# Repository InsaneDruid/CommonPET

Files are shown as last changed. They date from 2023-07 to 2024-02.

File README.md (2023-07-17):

# The CommonPET
The CommonPET is a 100% compatible replica of the SuperPet combo board for PET/CBM 8032 computers from 1981.
It implements all the features, including the 64K RAM addon, compatibility for the OS9 MMU well as the support for the internal RS-232 connector.

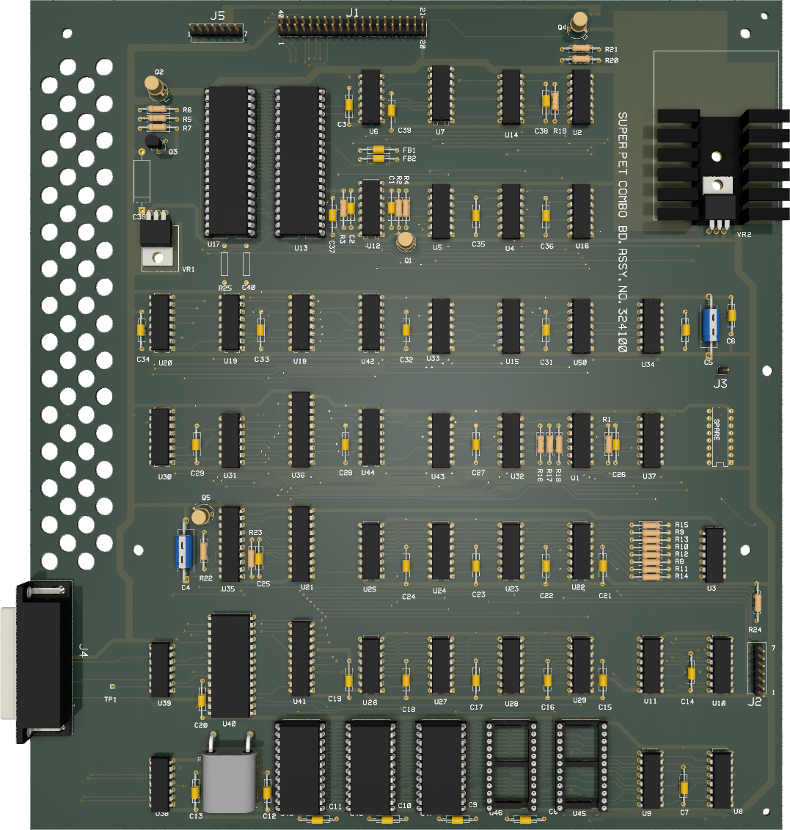
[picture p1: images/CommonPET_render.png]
CommonPET render


Most of the components are readily available. Chips not available from Mouser or Digikey can still be purchased as NOS from a variety of sources.

[Schematic](https://github.com/InsaneDruid/CommonPET/blob/main/CommonPET.pdf "Schematic")  

[Bill of Materials](https://htmlpreview.github.io/?https://github.com/InsaneDruid/CommonPET/blob/main/bom/CommonPET_bom.html "Bill of Materials")
## The Firmware
The Firmware of the SuperPET is available at zimmers.net: http://www.zimmers.net/anonftp/pub/cbm/firmware/computers/pet/SuperPET/index.html

UA3: characters.901640-01.bin (PETside CharROM):

U47: waterloo-a000-bfff.970018-12.bin

U48: waterloo-c000-dfff.970019-12.bin

U49: waterloo-e000-ffff-970034-12.bin (50Hz Version)

U49: waterloo-e000-ffff.970020-12.bin (60Hz Version)

Adapters to use 2764 EPROM work, 27hc641 that are programmed to be pin compatible to 2364 are recommended.

## The RS232 interface
CBM in its infinite wisdom only provided +5V and -9V for the 1488 line driver. A low voltage 1488E or 14C88 is recommended.

## The OS/9 MMU addon board
A replica of the OS/9 addon board can be found in the [os9_mmu folder](https://github.com/InsaneDruid/CommonPET/blob/main/os9_mmu/ "os9_mmu folder")

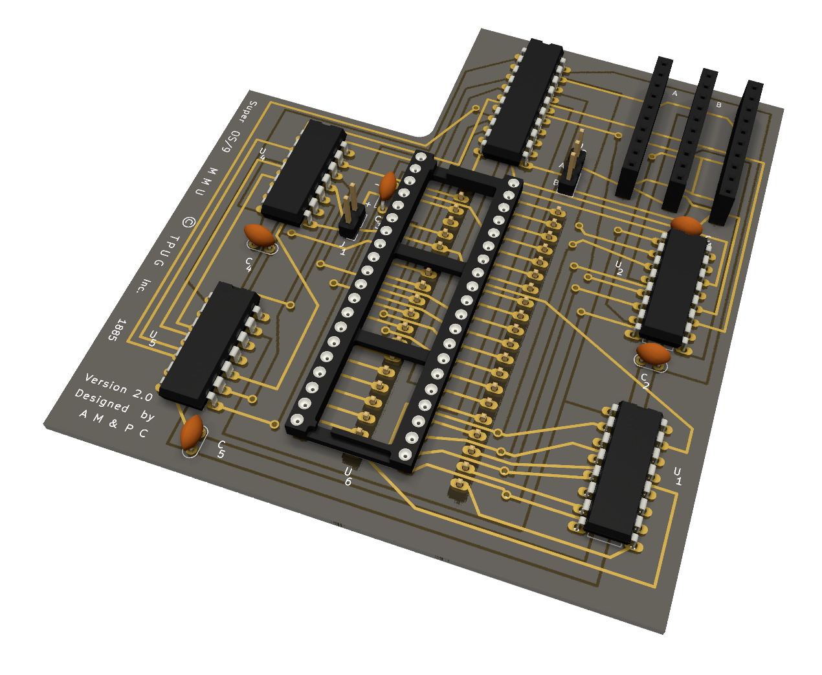
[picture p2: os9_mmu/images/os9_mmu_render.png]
OS/9 MMU addon board render
 

## The License
This work is licensed under a Creative Commons Attribution-ShareAlike 4.0 International License.  
See https://creativecommons.org/licenses/by-sa/4.0/.

## The Credits
This work would not have been possible without the help from a bunch of amazing people from [VzEkC e. V. forums](https://forum.classic-computing.de/forum/ "forum.classic-computing.de"). Many thanks go out to:

* *for(;;)* - for creating the amazing µMMF project that inspired this work
* *vossi* - for providing excellent images of a ASSY 324100 board
* *CBM_Ba* and *Richi*- for building and testing the first prototype

Special credits go out to *Mike Naberezny* for researching the OS/9 MMU schematics

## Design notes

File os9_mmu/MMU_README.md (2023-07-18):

## The OS/9 MMU
In the SuperPet system, the additional 64K of RAM is only accessible in 16 banks of 4KB, mapped in the $9000-9FFF address range (usually reserved for option ROMs) with a bank select register $EFFC.

The OS/9 MMU, designed by members of the Toronto PET Users Group (TPUG) expands the SuperPET expansion RAM bank select latch at $EFFC.

With the MMU installed, when bit 5 is set at $EFFC, the 6809 can access all of the 64K in the $0000-FFFF continuous address range.

# The three connector rows

The MMU interfaces with the SuperPet boards using the 6809 processor socket and the socket of the 74LS273 $EFFC latch IC controlling the memory bank select lines.

For the original, two-board SuperPet (U9) and the Comboboard Version (U36) different units of the total of eight flip flops contained in this IC had been used. Luckily, only one of the signals needed (EFFC) isn't mirror-symmetric between the two variants.

Thus, using only 3 Rows of connectors and one jumper is enough to be able to interface with either version of the SuperPet boards.

* For *ComboBoard SuperPets*, connect the ribbon cable going to the U36 Socket on the leftmost rows and set the jumper to 1-2. (Option A)
  
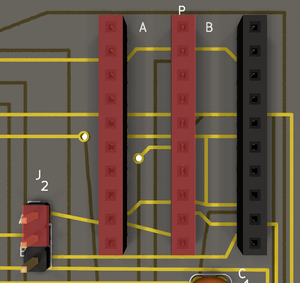
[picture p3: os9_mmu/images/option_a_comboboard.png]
OS/9 MMU addon board Option A
 
* For *two-board SuperPets*, connect the ribbon cable going to the U9 Socket on the rightmost rows and set the jumper to 2-3. (Option B)
  
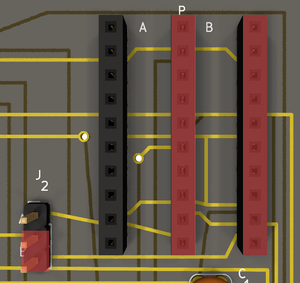
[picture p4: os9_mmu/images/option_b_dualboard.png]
OS/9 MMU addon board Option B


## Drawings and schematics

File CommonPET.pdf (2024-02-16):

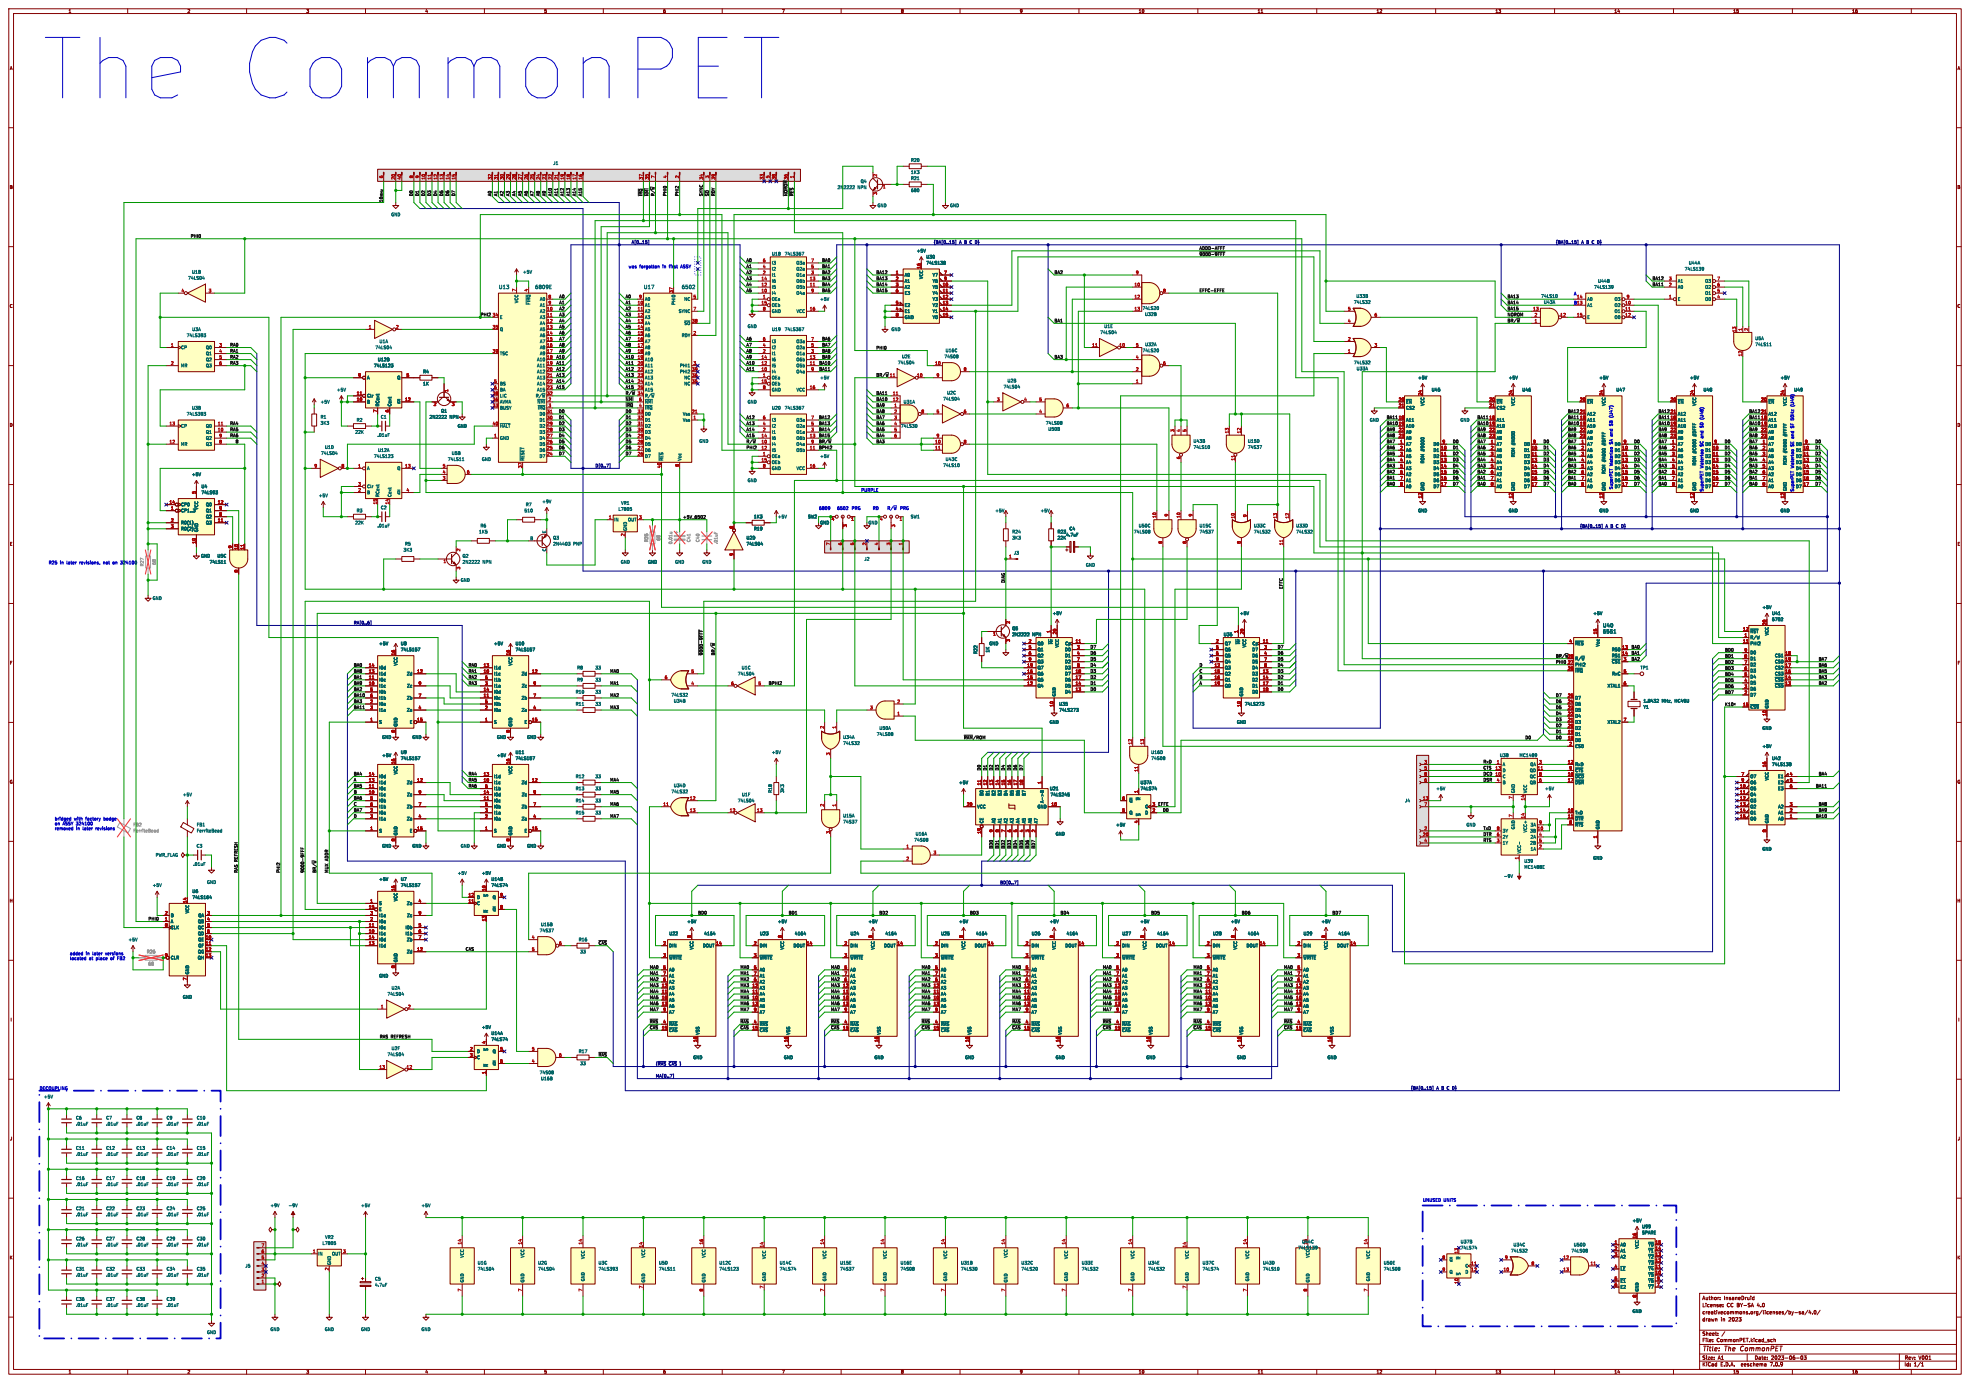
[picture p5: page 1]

bridged with factory bodge
on ASSY 324100
FB2 FerriteBead+5V
FerriteBead GND

removed in later revisions

8 A5 10 A4 11 A3 12 A6 13 DOUT 14 ~{CAS} 15 VSS 16 DIN 2 ~{WRITE} 3 ~{RAS} 4 A0 5 A2 6 A1 7 A7 9 U23 4164 +5VGND VCC 14 GND

8 A5 10 A4 11 A3 12 A6 13 DOUT 14 ~{CAS} 15 VSS 16 DIN 2 ~{WRITE} 3 ~{RAS} 4 A0 5 A2 6 A1 7 A7 9 U22 4164 VCC

8 A5 10 A4 11 A3 12 A6 13 DOUT 14 ~{CAS} 15 VSS 16 DIN 2 ~{WRITE} 3 ~{RAS} 4 A0 5 A2 6 A1 7 A7 9 GND

added in later versions

File: CommonPET.kicad_sch Sheet: / drawn in 2023

Id: 1/1 Title: The CommonPET

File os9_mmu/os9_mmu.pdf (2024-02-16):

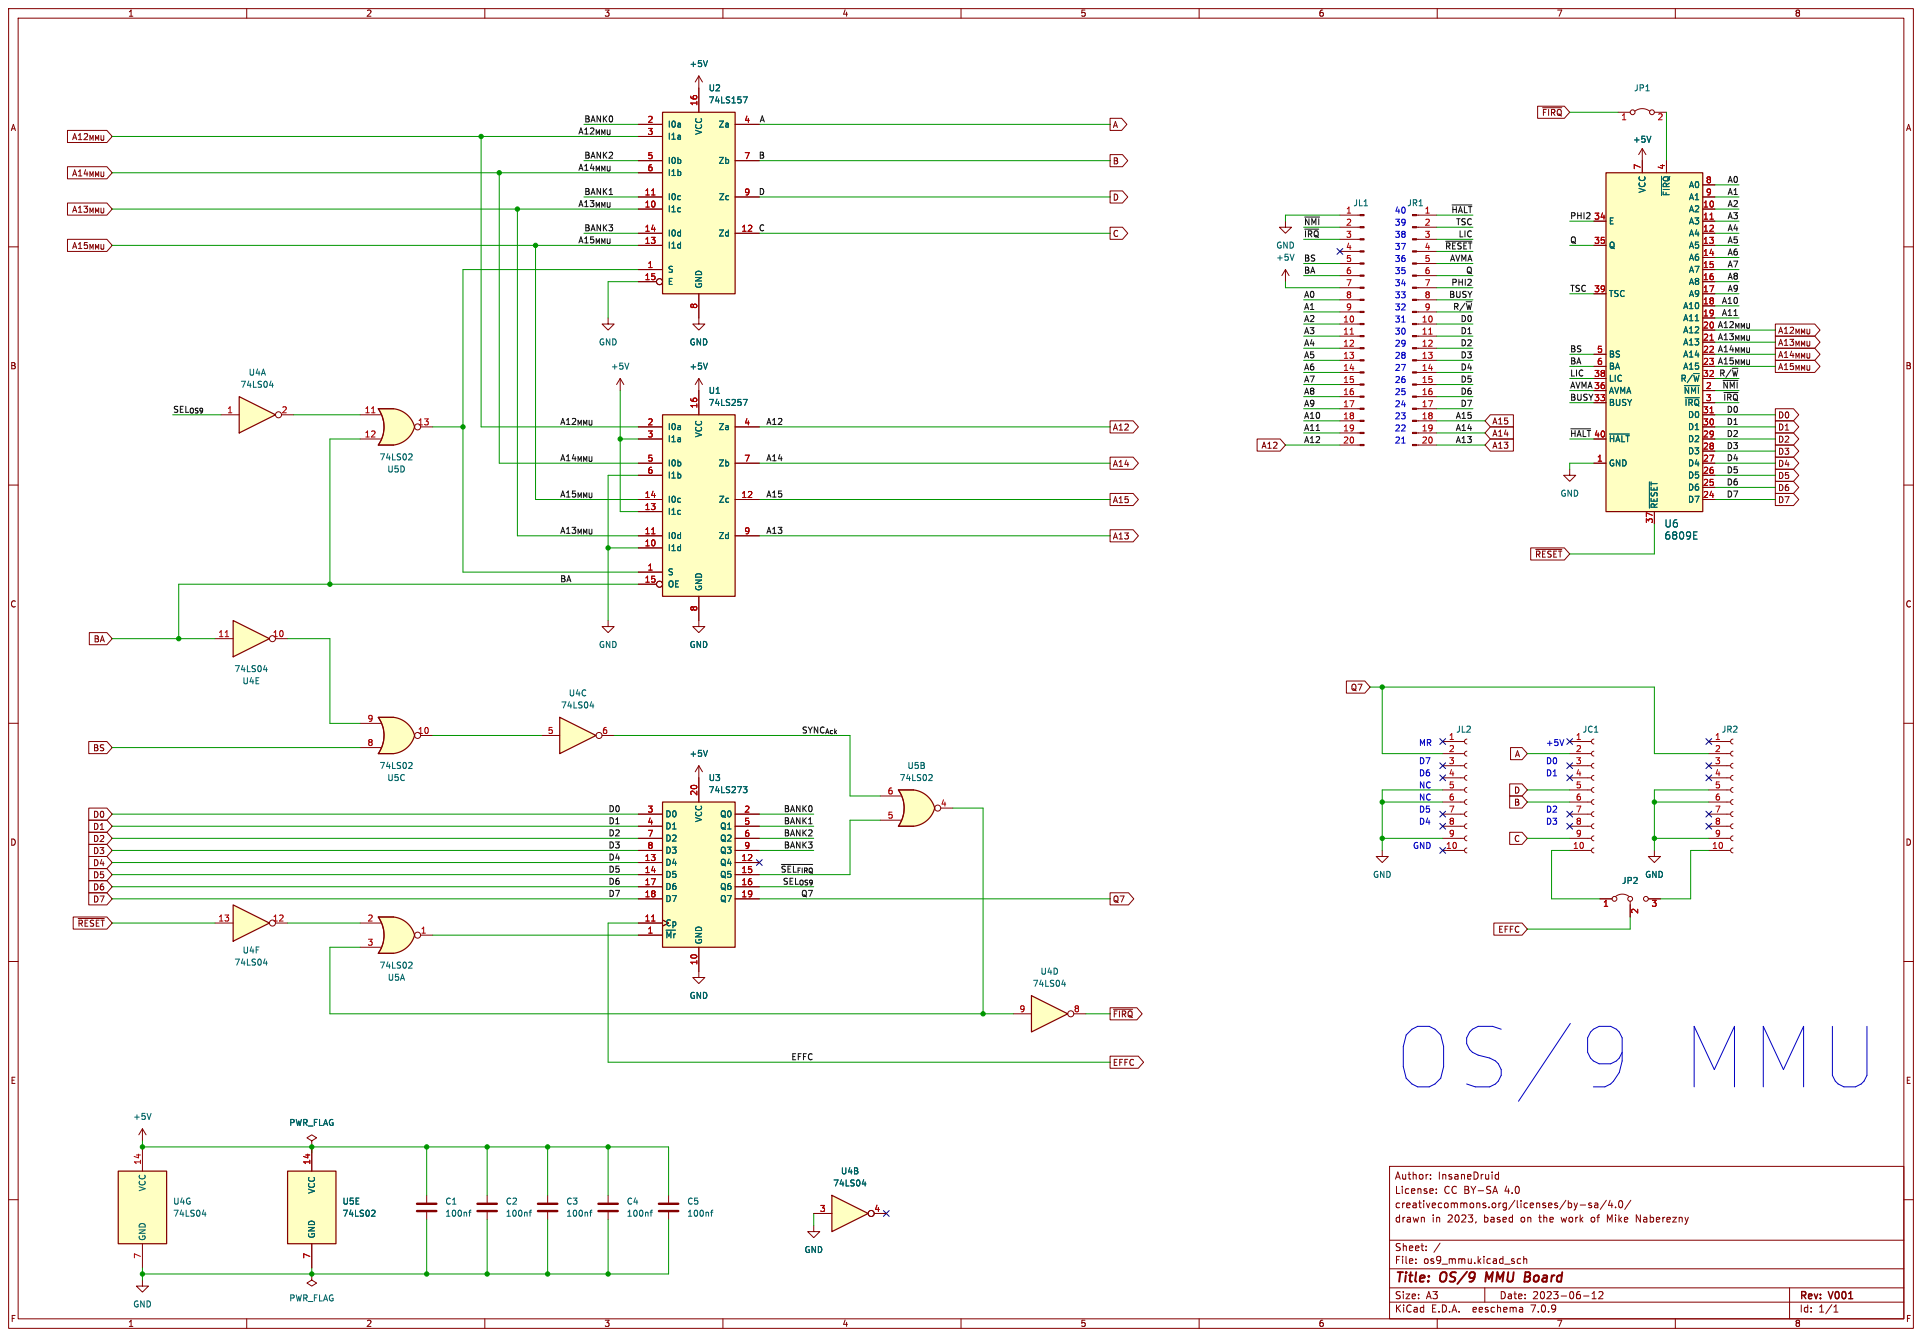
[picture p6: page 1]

Id: 1/1 Title: OS/9 MMU Board

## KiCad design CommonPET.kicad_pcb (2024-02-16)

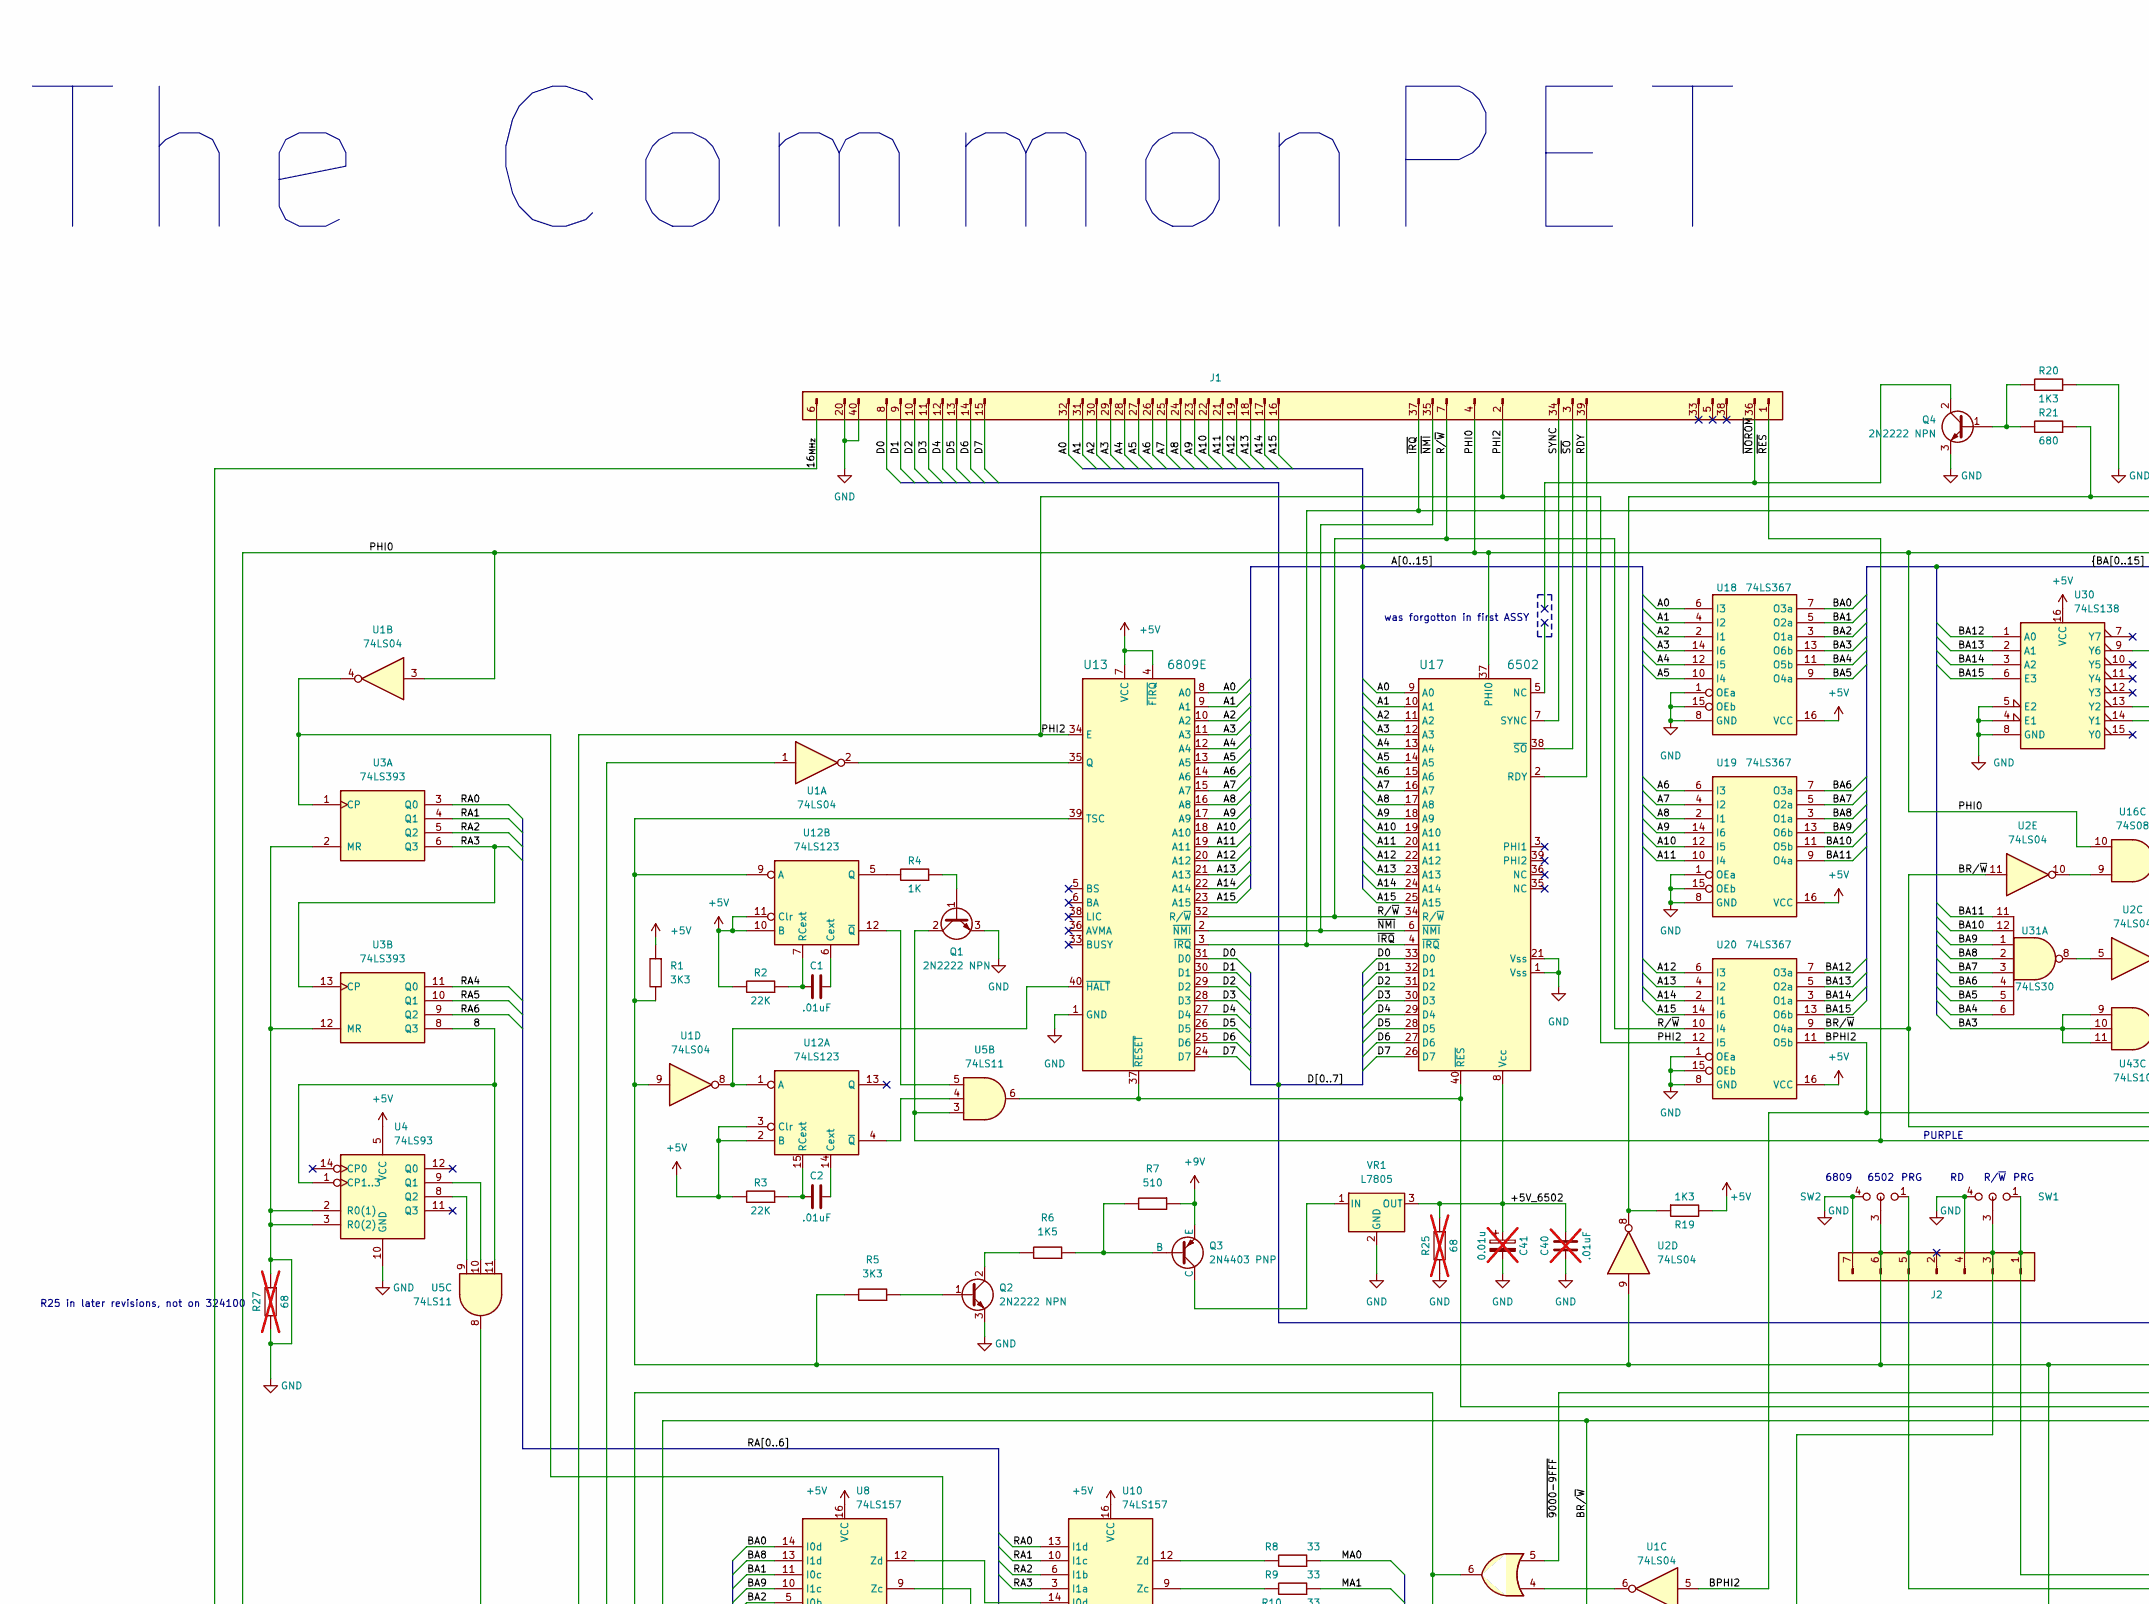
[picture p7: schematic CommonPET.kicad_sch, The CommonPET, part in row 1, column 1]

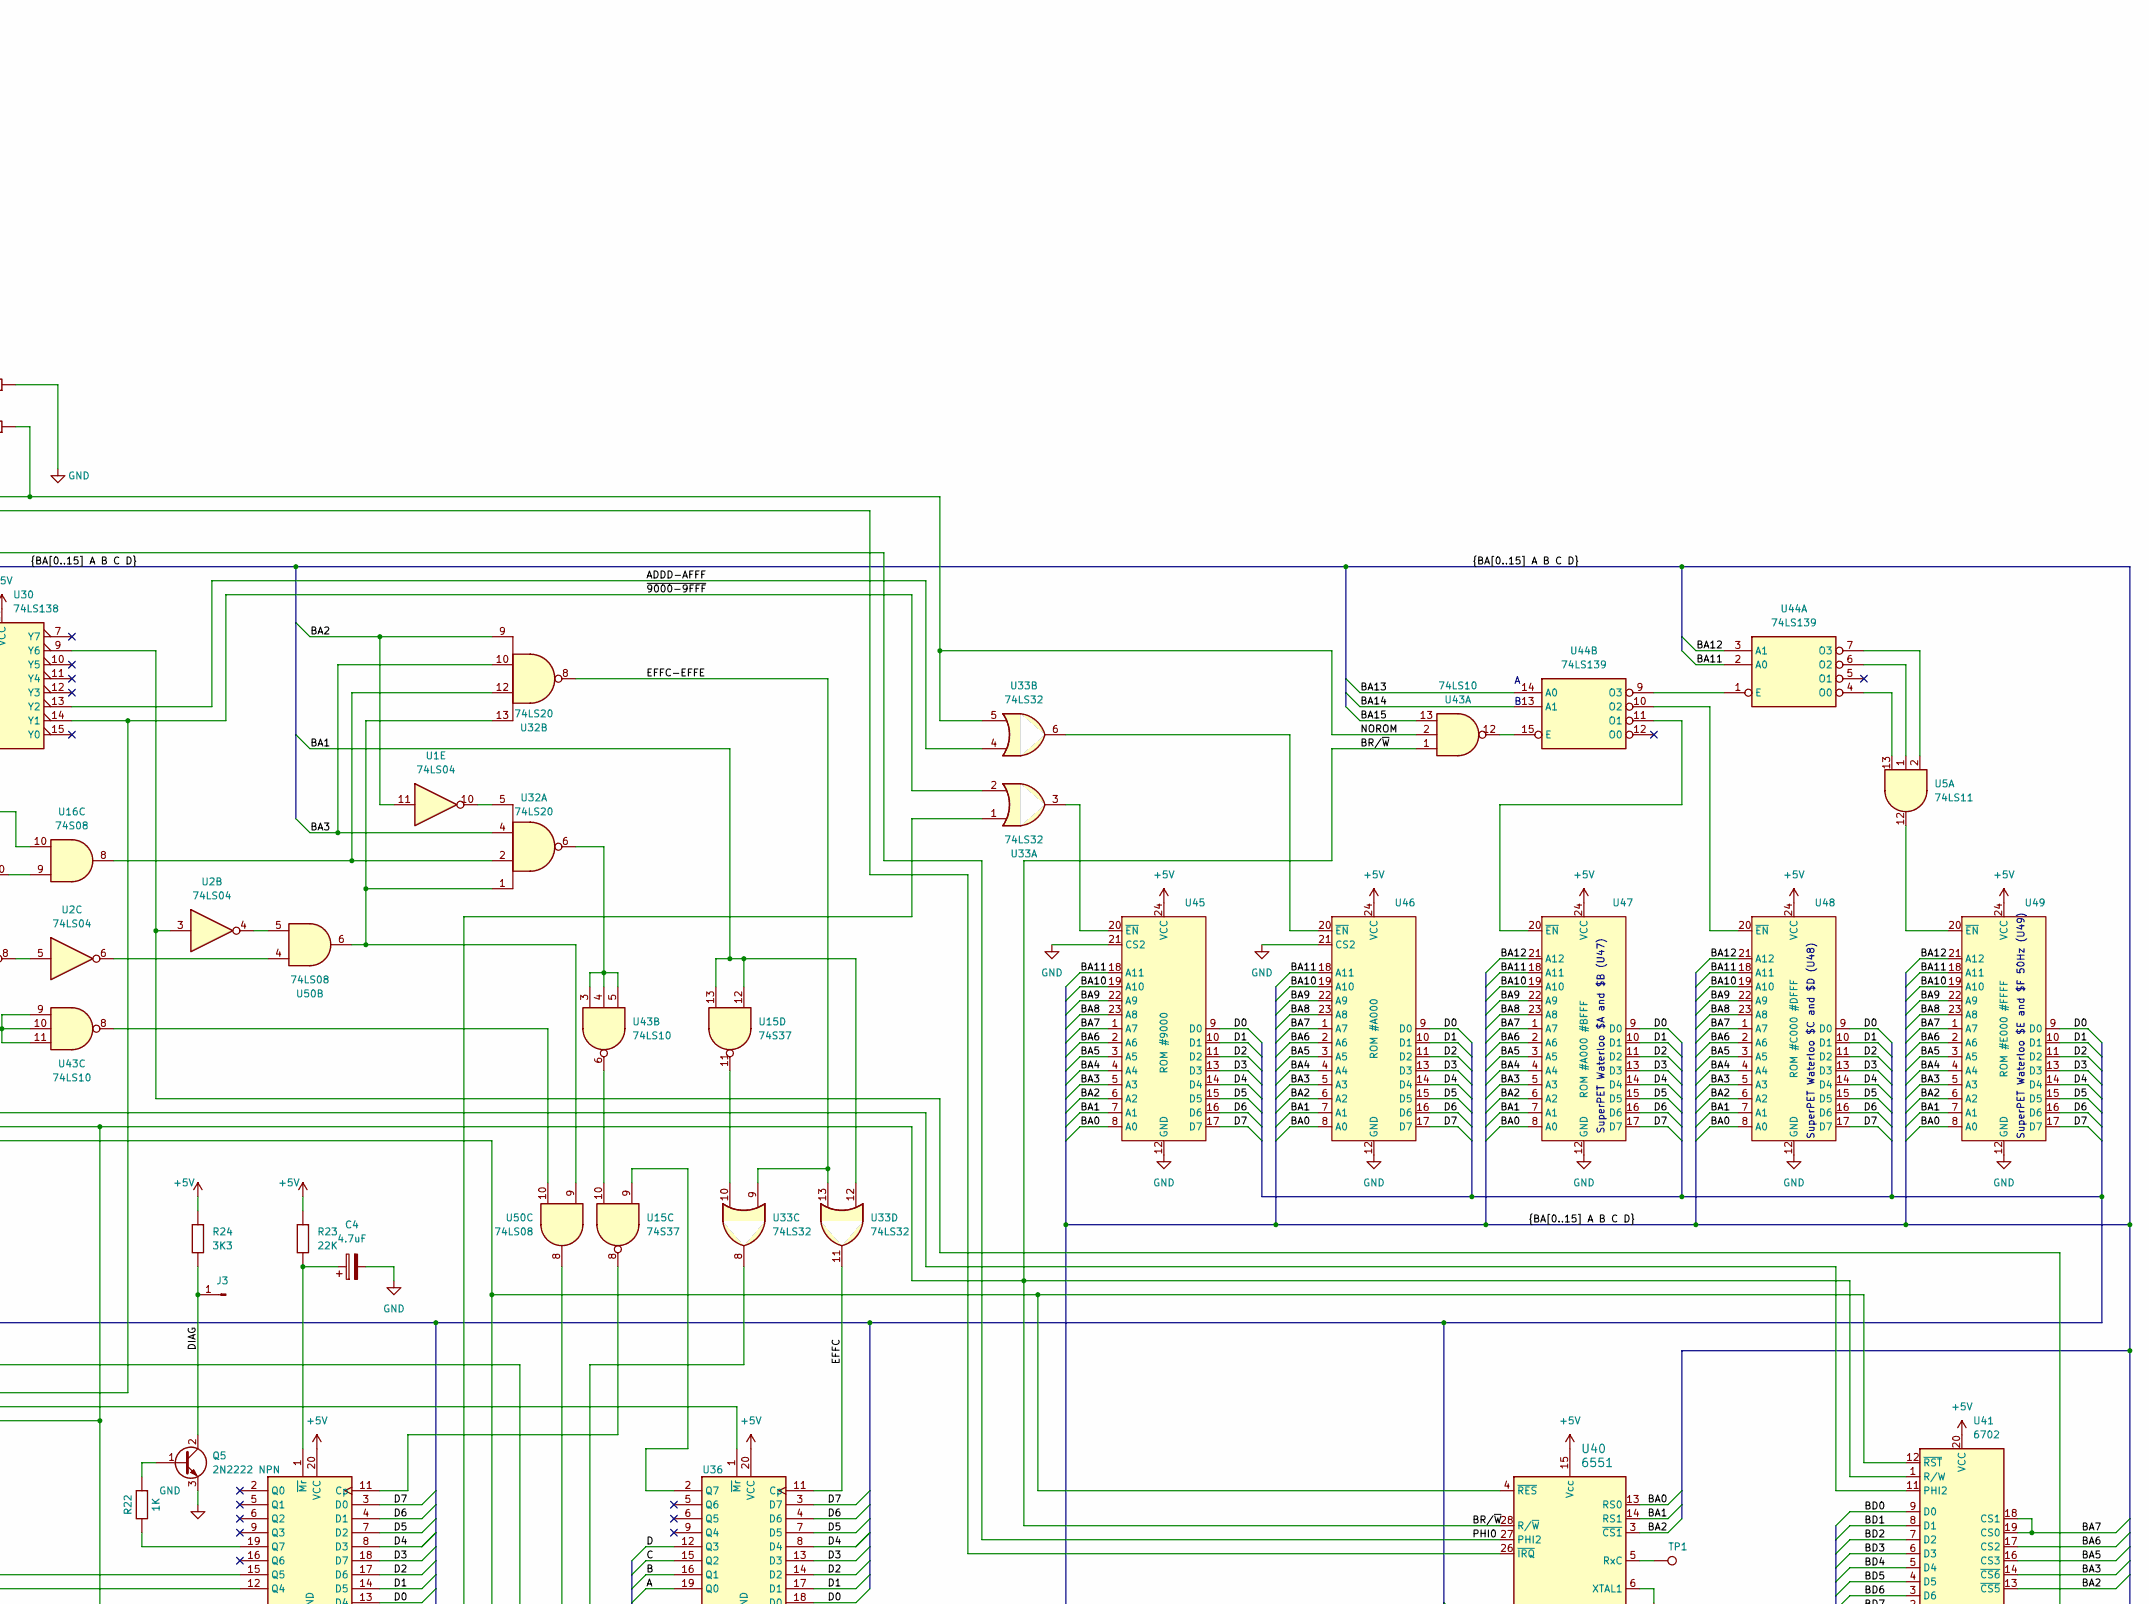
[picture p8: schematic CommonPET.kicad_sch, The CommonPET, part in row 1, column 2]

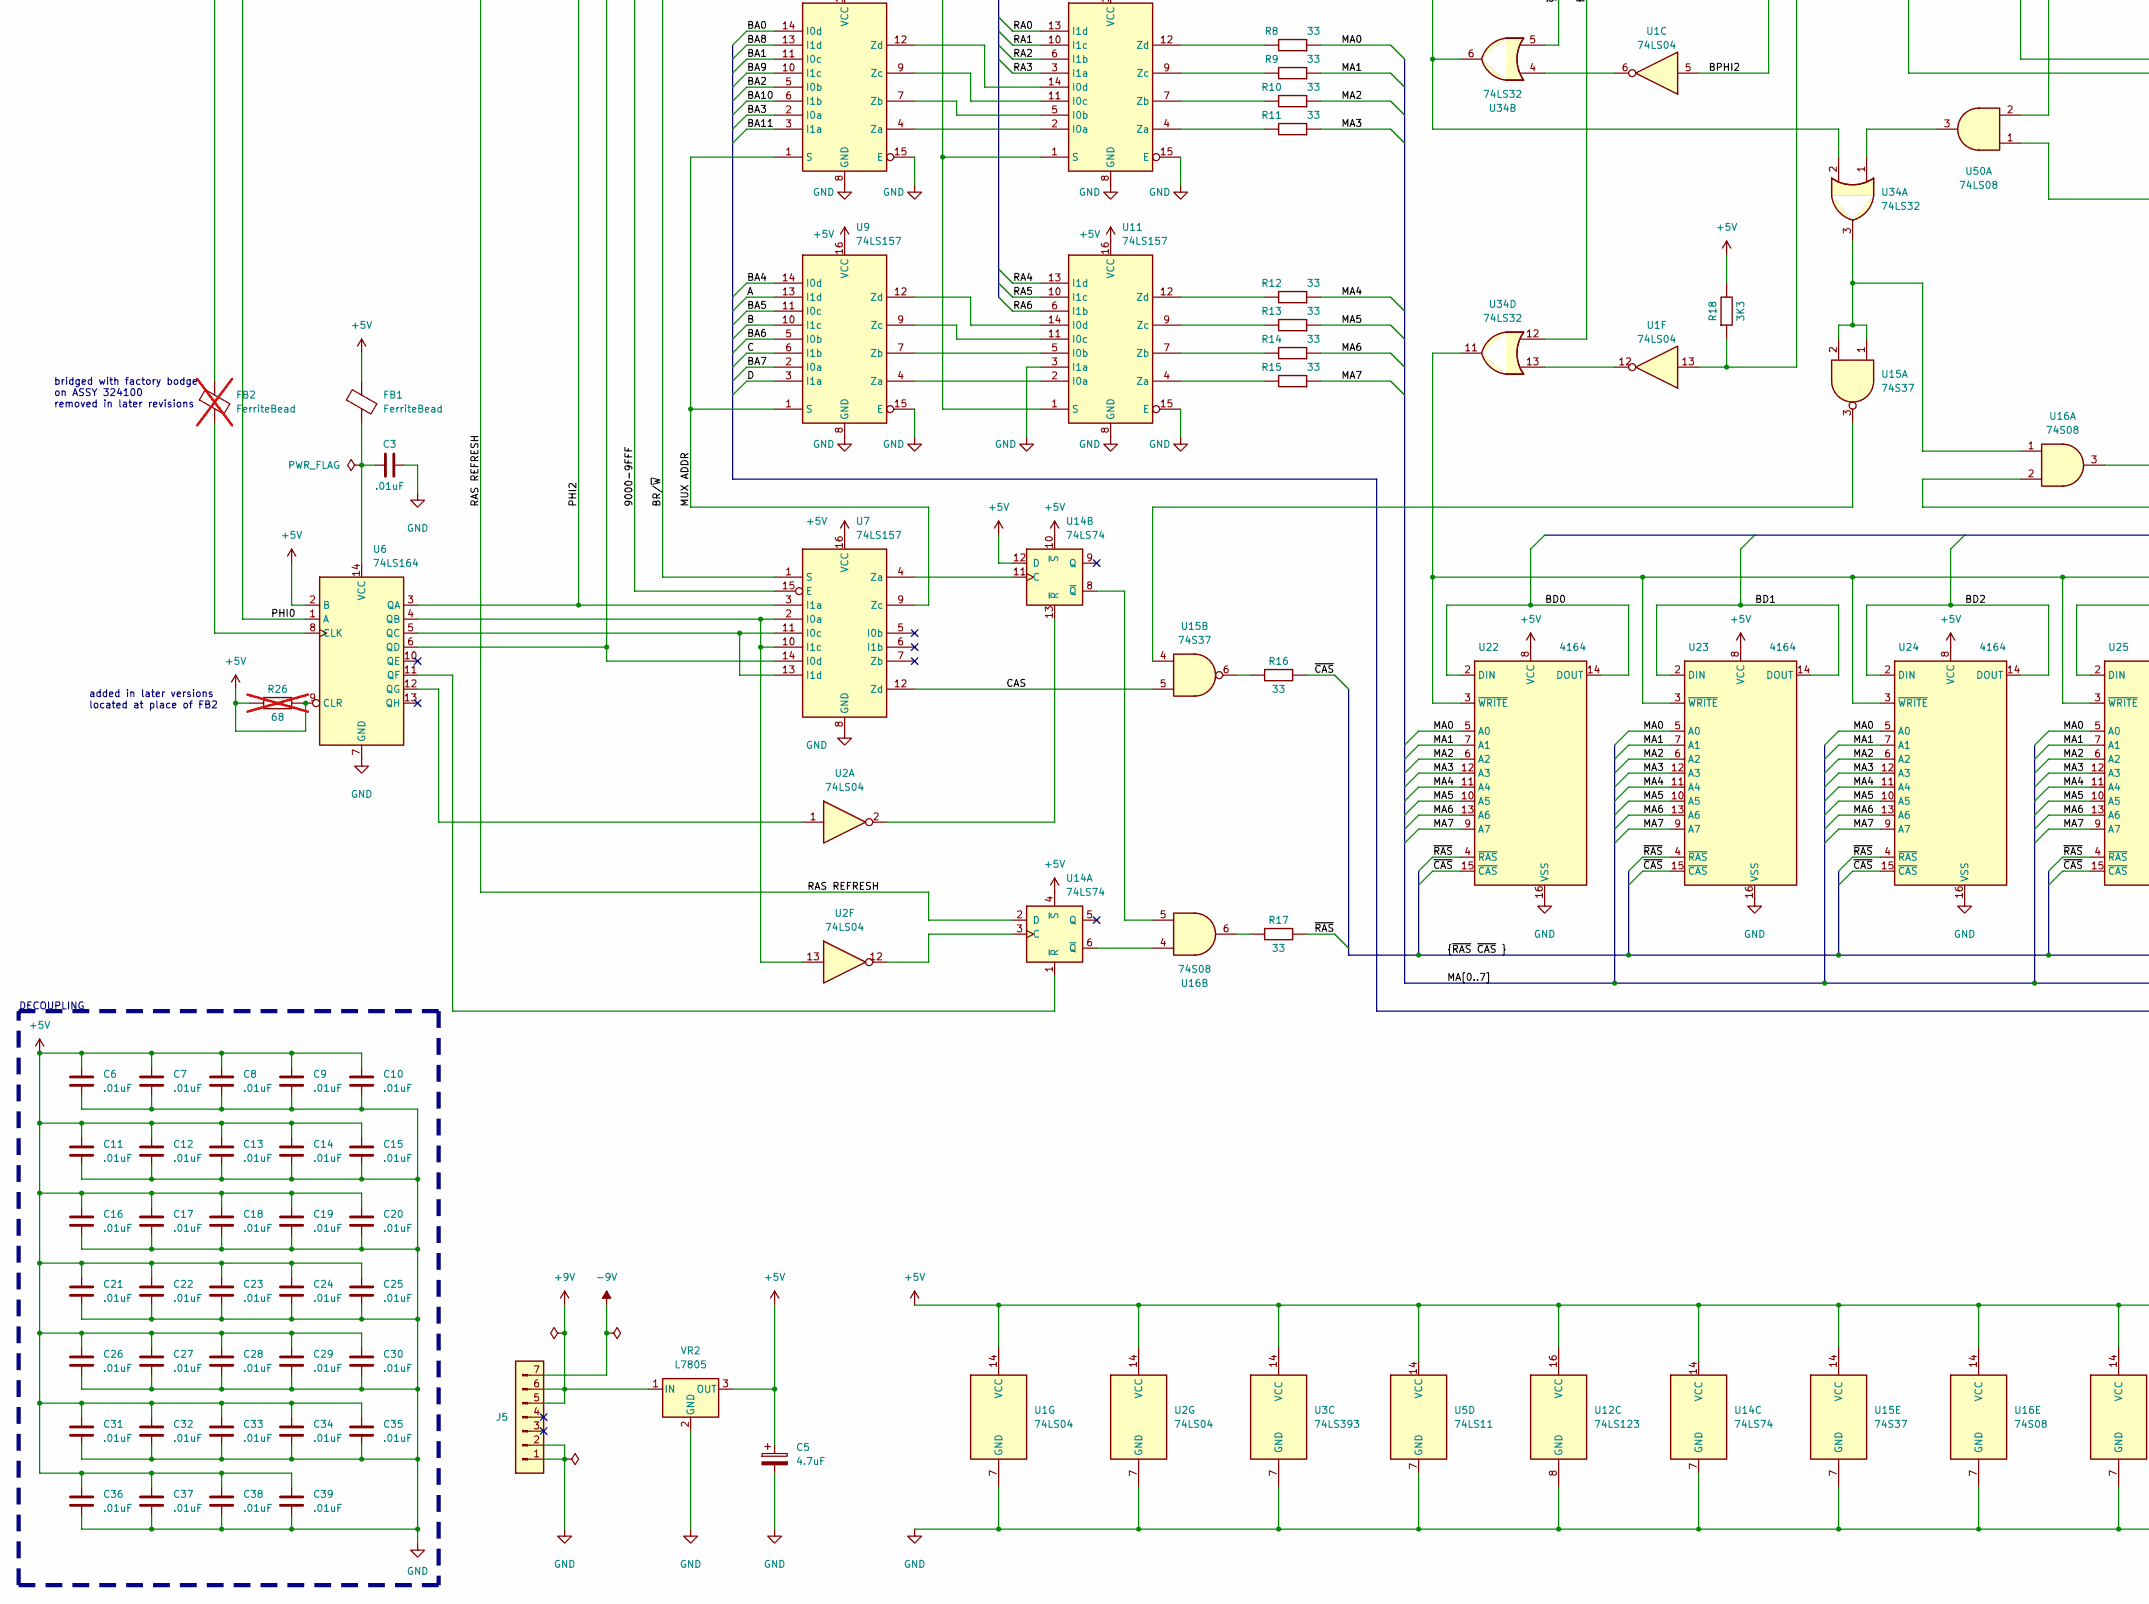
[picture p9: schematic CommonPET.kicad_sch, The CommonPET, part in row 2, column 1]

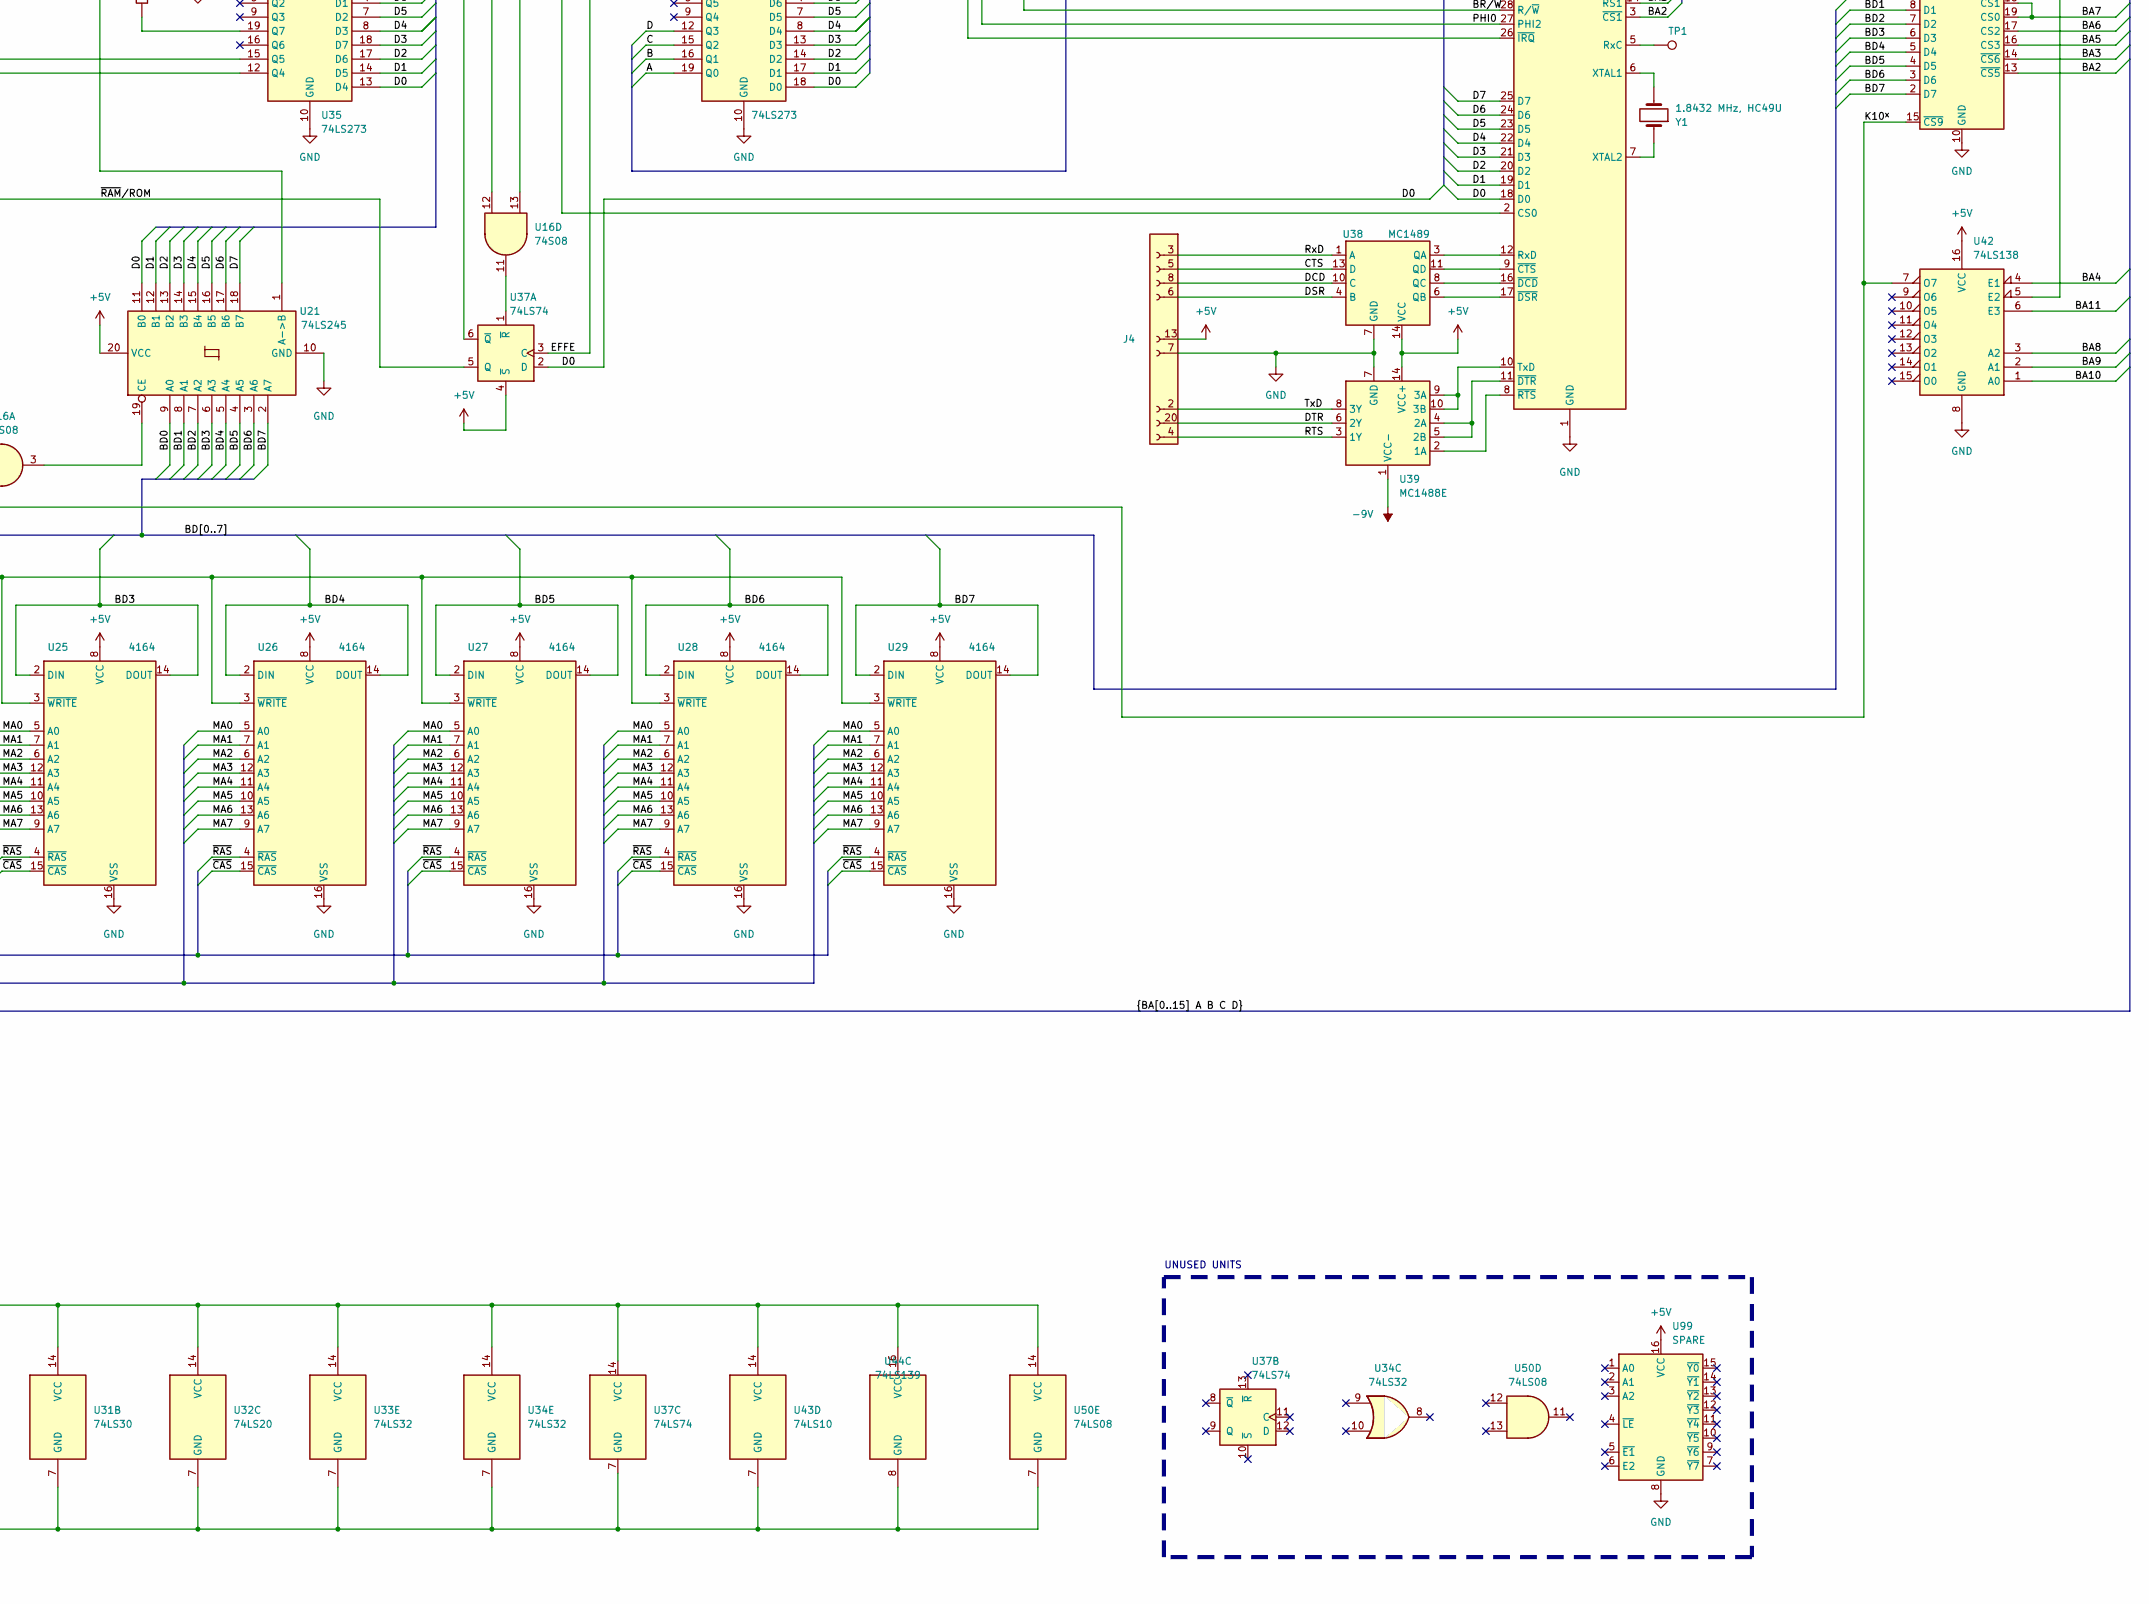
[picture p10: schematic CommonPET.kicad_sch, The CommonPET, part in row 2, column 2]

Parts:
C1, C2, C3, C6, C7, C8, C9, C10, C11, C12, C13, C14, C15, C16, C17, C18, C19, C20, C21, C22, C23, C24, C25, C26, C27, C28, C29, C30, C31, C32, C33, C34, C35, C36, C37, C38, C39: .01uF; C_Axial_L3.8mm_D2.6mm_P12.54mm_Horizontal
C4, C5: 4.7uF; CP_Axial_L11.0mm_D6.0mm_P20.32mm
C40: .01uF; C_Axial_L3.8mm_D2.6mm_P12.54mm_Horizontal_notpopulated; not fitted
C41: 0.01u; CP_Axial_L11.0mm_D6.0mm_P20.32mm_notpopulated; not fitted
FB1: FerriteBead; C_Axial_L3.8mm_D2.6mm_P12.54mm_Horizontal
FB2: FerriteBead; C_Axial_L3.8mm_D2.6mm_P12.54mm_Horizontal; not fitted
J1: Conn_01x40_Pin; PinHeader_2x20_P2.54mm_Vertical
J2, J5: Conn_01x07_Pin; PinHeader_1x07_P2.54mm_Vertical
J3: Conn_01x01_Pin; PinHeader_1x01_P2.54mm_Vertical
J4: Conn_01x25_Socket; DSUB-25_Female_Horizontal_P2.77x2.84mm_EdgePinOffset9.90mm_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
Q1, Q2, Q4, Q5: 2N2222 NPN; TO-18-3
Q3: 2N4403 PNP; TO-92
R1, R5, R18, R24: 3K3; R_Axial_DIN0207_L6.3mm_D2.5mm_P15.24mm_Horizontal
R2, R3, R23: 22K; R_Axial_DIN0207_L6.3mm_D2.5mm_P15.24mm_Horizontal
R4, R22: 1K; R_Axial_DIN0207_L6.3mm_D2.5mm_P15.24mm_Horizontal
R6: 1K5; R_Axial_DIN0207_L6.3mm_D2.5mm_P15.24mm_Horizontal
R7: 510; R_Axial_DIN0207_L6.3mm_D2.5mm_P15.24mm_Horizontal
R8, R9, R10, R11, R12, R13, R14, R15, R16, R17: 33; R_Axial_DIN0207_L6.3mm_D2.5mm_P15.24mm_Horizontal
R19, R20: 1K3; R_Axial_DIN0207_L6.3mm_D2.5mm_P15.24mm_Horizontal
R21: 680; R_Axial_DIN0207_L6.3mm_D2.5mm_P15.24mm_Horizontal
R25: 68; R_Axial_DIN0207_L6.3mm_D2.5mm_P15.24mm_Horizontal__notpopul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; not fitted
R26, R27: 68; R_Axial_DIN0207_L6.3mm_D2.5mm_P15.24mm_Horizontal; not fitted
SW1, SW2: SW_DP3T
TP1: TestPoint; TestPoint_THTPad_1.0x1.0mm_Drill0.5mm
U1, U2: 74LS04; DIP-14_W7.62mm
U3: 74LS393; DIP-14_W7.62mm
U4: 74LS93; DIP-14_W7.62mm
U5: 74LS11; DIP-14_W7.62mm
U6: 74LS164; DIP-14_W7.62mm
U7, U8, U9, U10, U11: 74LS157; DIP-16_W7.62mm
U12: 74LS123; DIP-16_W7.62mm
U13: 6809E; DIP-40_W15.24mm_socket
U14, U37: 74LS74; DIP-14_W7.62mm
U15: 74S37; DIP-14_W7.62mm
U16: 74S08; DIP-14_W7.62mm
U17: 6502; DIP-40_W15.24mm_socket
U18, U19, U20: 74LS367; DIP-16_W7.62mm
U21: 74LS245; DIP-20_W7.62mm
U22, U23, U24, U25, U26, U27, U28, U29: 4164; DIP-16_W7.62mm
U30, U42: 74LS138; DIP-16_W7.62mm
U31: 74LS30; DIP-14_W7.62mm
U32: 74LS20; DIP-14_W7.62mm
U33, U34: 74LS32; DIP-14_W7.62mm
U35, U36: 74LS273; DIP-20_W7.62mm
U38: MC1489; DIP-14_W7.62mm
U39: MC1488E; DIP-14_W7.62mm
U40: 6551; DIP-28_W15.24mm
U41: 6702; DIP-20_W7.62mm
U43: 74LS10; DIP-14_W7.62mm
U44: 74LS139; DIP-16_W7.62mm
U45: ROM #9000; DIP-24_W15.24mm_socket
U46: ROM #A000; DIP-24_W15.24mm_socket
U47: ROM #A000 #BFFF; DIP-24_W15.24mm
U48: ROM #C000 #DFFF; DIP-24_W15.24mm
U49: ROM #E000 #FFFF; DIP-24_W15.24mm
U50: 74LS08; DIP-14_W7.62mm
U99: SPARE; SPARE_DIP-16_W7.62mm
VR1: L7805; TO-220-3_Horizontal_TabDown
VR2: L7805; TO-220-3_Horizontal_TabDown_HeatSinked
Y1: 1.8432 MHz, HC49U; Crystal_HC33-U_Horizontal

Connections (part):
+5V: C5.1, C6.1, C7.1, C8.1, C9.1, C10.1, C11.1, C12.2, C13.2, C14.1, C15.1, C16.1, C17.1, C18.1, C19.1, C20.1, C21.1, C22.1, C23.1, C24.1, C25.1, C26.1, C27.1, C28.1, C29.1, C30.1, C31.1, C32.1, C33.1, C34.1, C35.1, C36.1, C37.1, C38.1, C39.1, FB1.1, J4.13 (Pin_7), R1.2, R2.1, R3.1, R18.1, R19.1, R23.2, R24.2, U1.14 (VCC), U2.14 (VCC), U3.14 (VCC), U4.5 (VCC), U5.14 (VCC), U6.2 (B), U6.9 (CLR), U7.16 (VCC), U8.16 (VCC), U9.16 (VCC), U10.16 (VCC), U11.16 (VCC), U12.2 (B), U12.3 (Clr), U12.10 (B), U12.11 (Clr), U12.16 (VCC), U13.4 (~FIRQ), U13.7 (VCC), U14.4 (~S), U14.10 (~S), U14.12 (D), U14.14 (VCC), U15.14 (VCC), U16.14 (VCC), U18.16 (VCC), U19.16 (VCC), U20.16 (VCC), U21.20 (VCC), U22.8 (VCC), U23.8 (VCC), U24.8 (VCC), U25.8 (VCC), U26.8 (VCC), U27.8 (VCC), U28.8 (VCC)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
+9V: J5.5, J5.6, Q3.3 (E), R7.2, VR2.1 (IN)
-9V: J5.7, U39.1 (VCC-)
/8: U3.8 (Q3), U4.1 (CP1..3), U5.11
/16_{MHz}: FB2.1, J1.6
/9000-9FFF: U7.15 (E), U34.2, U34.6
/+5V_6502: C40.2, C41.1, R25.2, U17.8 (Vcc), VR1.3 (OUT)
/A: U9.13 (I1d), U36.19 (Q0)
/A0: J1.32, U13.8 (A0), U17.9 (A0), U18.6 (I3)
/A1: J1.31, U13.9 (A1), U17.10 (A1), U18.4 (I2)
/A2: J1.30, U13.10 (A2), U17.11 (A2), U18.2 (I1)
/A3: J1.29, U13.11 (A3), U17.12 (A3), U18.14 (I6)
/A4: J1.28, U13.12 (A4), U17.13 (A4), U18.12 (I5)
/A5: J1.27, U13.13 (A5), U17.14 (A5), U18.10 (I4)
/A6: J1.26, U13.14 (A6), U17.15 (A6), U19.6 (I3)
/A7: J1.25, U13.15 (A7), U17.16 (A7), U19.4 (I2)
/A8: J1.24, U13.16 (A8), U17.17 (A8), U19.2 (I1)
/A9: J1.23, U13.17 (A9), U17.18 (A9), U19.14 (I6)
/A10: J1.22, U13.18 (A10), U17.19 (A10), U19.12 (I5)
/A11: J1.21, U13.19 (A11), U17.20 (A11), U19.10 (I4)
/A12: J1.19, U13.20 (A12), U17.22 (A12), U20.6 (I3)
/A13: J1.18, U13.21 (A13), U17.23 (A13), U20.4 (I2)
/A14: J1.17, U13.22 (A14), U17.24 (A14), U20.2 (I1)
/A15: J1.16, U13.23 (A15), U17.25 (A15), U20.14 (I6)
/ADDD-AFFF: U30.13 (Y2), U33.4
/B: U9.10 (I1c), U36.16 (Q1)
/BA0: U8.14 (I0d), U18.7 (O3a), U40.13 (RS0), U45.8 (A0), U46.8 (A0), U47.8 (A0), U48.8 (A0), U49.8 (A0)
/BA1: U8.11 (I0c), U15.12, U15.13, U18.5 (O2a), U33.12, U40.14 (RS1), U45.7 (A1), U46.7 (A1), U47.7 (A1), U48.7 (A1), U49.7 (A1)
/BA2: U1.11, U8.5 (I0b), U18.3 (O1a), U32.9, U40.3 (~CS1), U41.13 (~CS5), U45.6 (A2), U46.6 (A2), U47.6 (A2), U48.6 (A2), U49.6 (A2)
/BA3: U8.2 (I0a), U18.13 (O6b), U32.4, U32.10, U41.14 (~CS6), U43.9, U43.10, U43.11, U45.5 (A3), U46.5 (A3), U47.5 (A3), U48.5 (A3), U49.5 (A3)
/BA4: U9.14 (I0d), U18.11 (O5b), U31.6, U42.4 (E1), U45.4 (A4), U46.4 (A4), U47.4 (A4), U48.4 (A4), U49.4 (A4)
/BA5: U9.11 (I0c), U18.9 (O4a), U31.5, U41.16 (CS3), U45.3 (A5), U46.3 (A5), U47.3 (A5), U48.3 (A5), U49.3 (A5)
/BA6: U9.5 (I0b), U19.7 (O3a), U31.4, U41.17 (CS2), U45.2 (A6), U46.2 (A6), U47.2 (A6), U48.2 (A6), U49.2 (A6)
/BA7: U9.2 (I0a), U19.5 (O2a), U31.3, U41.18 (CS1), U41.19 (CS0), U45.1 (A7), U46.1 (A7), U47.1 (A7), U48.1 (A7), U49.1 (A7)
/BA8: U8.13 (I1d), U19.3 (O1a), U31.2, U42.3 (A2), U45.23 (A8), U46.23 (A8), U47.23 (A8), U48.23 (A8), U49.23 (A8)
/BA9: U8.10 (I1c), U19.13 (O6b), U31.1, U42.2 (A1), U45.22 (A9), U46.22 (A9), U47.22 (A9), U48.22 (A9), U49.22 (A9)
/BA10: U8.6 (I1b), U19.11 (O5b), U31.12, U42.1 (A0), U45.19 (A10), U46.19 (A10), U47.19 (A10), U48.19 (A10), U49.19 (A10)
/BA11: U8.3 (I1a), U19.9 (O4a), U31.11, U42.6 (E3), U44.2 (A0), U45.18 (A11), U46.18 (A11), U47.18 (A11), U48.18 (A11), U49.18 (A11)
/BA12: U20.7 (O3a), U30.1 (A0), U44.3 (A1), U47.21 (A12), U48.21 (A12), U49.21 (A12)
/BA13: U20.5 (O2a), U30.2 (A1), U44.14 (A0)
/BA14: U20.3 (O1a), U30.3 (A2), U44.13 (A1)
/BA15: U20.13 (O6b), U30.6 (E3), U43.13
/BD0: U21.9 (A0), U22.2 (DIN), U22.14 (DOUT), U41.9 (D0)
/BD1: U21.8 (A1), U23.2 (DIN), U23.14 (DOUT), U41.8 (D1)
/BD2: U21.7 (A2), U24.2 (DIN), U24.14 (DOUT), U41.7 (D2)
/BD3: U21.6 (A3), U25.2 (DIN), U25.14 (DOUT), U41.6 (D3)
/BD4: U21.5 (A4), U26.2 (DIN), U26.14 (DOUT), U41.5 (D4)
/BD5: U21.4 (A5), U27.2 (DIN), U27.14 (DOUT), U41.4 (D5)
/BD6: U21.3 (A6), U28.2 (DIN), U28.14 (DOUT), U41.3 (D6)
/BD7: U21.2 (A7), U29.2 (DIN), U29.14 (DOUT), U41.2 (D7)
/BPHI2: U1.5, U20.11 (O5b), U41.11 (PHI2)
/BR/~W: U2.11, U7.1 (S), U20.9 (O4a), U21.1 (A->B), U34.12, U40.28 (R/~W), U41.1 (R/W), U43.1
/C: U9.6 (I1b), U36.15 (Q2)
/CAS: U7.12 (Zd), U15.5
/CTS: J4.5, U38.13 (D)
/D: U9.3 (I1a), U36.12 (Q3)
/D0: J1.8, U13.31 (D0), U17.33 (D0), U21.11 (B0), U35.13 (D4), U36.18 (D0), U37.2 (D), U40.18 (D0), U45.9 (D0), U46.9 (D0), U47.9 (D0), U48.9 (D0), U49.9 (D0)
/D1: J1.9, U13.30 (D1), U17.32 (D1), U21.12 (B1), U35.14 (D5), U36.17 (D1), U40.19 (D1), U45.10 (D1), U46.10 (D1), U47.10 (D1), U48.10 (D1), U49.10 (D1)
/D2: J1.10, U13.29 (D2), U17.31 (D2), U21.13 (B2), U35.17 (D6), U36.14 (D2), U40.20 (D2), U45.11 (D2), U46.11 (D2), U47.11 (D2), U48.11 (D2), U49.11 (D2)
/D3: J1.11, U13.28 (D3), U17.30 (D3), U21.14 (B3), U35.18 (D7), U36.13 (D3), U40.21 (D3), U45.13 (D3), U46.13 (D3), U47.13 (D3), U48.13 (D3), U49.13 (D3)
/D4: J1.12, U13.27 (D4), U17.29 (D4), U21.15 (B4), U35.8 (D3), U36.8 (D4), U40.22 (D4), U45.14 (D4), U46.14 (D4), U47.14 (D4), U48.14 (D4), U49.14 (D4)
/D5: J1.13, U13.26 (D5), U17.28 (D5), U21.16 (B5), U35.7 (D2), U36.7 (D5), U40.23 (D5), U45.15 (D5), U46.15 (D5), U47.15 (D5), U48.15 (D5), U49.15 (D5)
/D6: J1.14, U13.25 (D6), U17.27 (D6), U21.17 (B6), U35.4 (D1), U36.4 (D6), U40.24 (D6), U45.16 (D6), U46.16 (D6), U47.16 (D6), U48.16 (D6), U49.16 (D6)
/D7: J1.15, U13.24 (D7), U17.26 (D7), U21.18 (B7), U35.3 (D0), U36.3 (D7), U40.25 (D7), U45.17 (D7), U46.17 (D7), U47.17 (D7), U48.17 (D7), U49.17 (D7)
/DCD: J4.8, U38.10 (C)
/DIAG: J3.1, Q5.2 (C), R24.1
/DSR: J4.6, U38.4 (B)
/DTR: J4.20, U39.6 (2Y)
/EFFC: U33.11, U36.11 (Cp)
/EFFC-EFFE: U32.8, U33.9, U33.13
/EFFE: U33.8, U37.3 (C)
/K10^{x}: U16.2, U41.15 (~CS9), U42.7 (O7)
/MA0: R8.2, U22.5 (A0), U23.5 (A0), U24.5 (A0), U25.5 (A0), U26.5 (A0), U27.5 (A0), U28.5 (A0), U29.5 (A0)
/MA1: R9.2, U22.7 (A1), U23.7 (A1), U24.7 (A1), U25.7 (A1), U26.7 (A1), U27.7 (A1), U28.7 (A1), U29.7 (A1)
/MA2: R10.2, U22.6 (A2), U23.6 (A2), U24.6 (A2), U25.6 (A2), U26.6 (A2), U27.6 (A2), U28.6 (A2), U29.6 (A2)
/MA3: R11.2, U22.12 (A3), U23.12 (A3), U24.12 (A3), U25.12 (A3), U26.12 (A3), U27.12 (A3), U28.12 (A3), U29.12 (A3)
/MA4: R12.2, U22.11 (A4), U23.11 (A4), U24.11 (A4), U25.11 (A4), U26.11 (A4), U27.11 (A4), U28.11 (A4), U29.11 (A4)
/MA5: R13.2, U22.10 (A5), U23.10 (A5), U24.10 (A5), U25.10 (A5), U26.10 (A5), U27.10 (A5), U28.10 (A5), U29.10 (A5)
/MA6: R14.2, U22.13 (A6), U23.13 (A6), U24.13 (A6), U25.13 (A6), U26.13 (A6), U27.13 (A6), U28.13 (A6), U29.13 (A6)
/MA7: R15.2, U22.9 (A7), U23.9 (A7), U24.9 (A7), U25.9 (A7), U26.9 (A7), U27.9 (A7), U28.9 (A7), U29.9 (A7)
/MUX ADDR: U7.9 (Zc), U8.1 (S), U9.1 (S)
/NOROM: R19.2, R21.2, U2.8, U33.5, U43.2
/PHI0: J1.4, U1.3, U6.1 (A), U16.10, U17.37 (PHI0), U40.27 (PHI2)
/PHI2: J1.2, U6.3 (QA), U7.3 (I1a), U13.34 (E), U20.12 (I5)
/RA0: U3.3 (Q0), U10.13 (I1d)
/RA1: U3.4 (Q1), U10.10 (I1c)
/RA2: U3.5 (Q2), U10.6 (I1b)
/RA3: U3.6 (Q3), U3.13 (CP), U10.3 (I1a)
/RA4: U3.11 (Q0), U11.13 (I1d)
/RA5: U3.10 (Q1), U11.10 (I1c)
/RA6: U3.9 (Q2), U11.6 (I1b)
/RAS REFRESH: U5.8, U14.2 (D)
/RDY: J1.39, U17.2 (RDY)
/RTS: J4.4, U39.3 (1Y)
/RxD: J4.3, U38.1 (A)
/R/~W: J1.7, U13.32 (R/~W), U17.34 (R/~W), U20.10 (I4)
/SYNC: J1.34, U17.7 (SYNC)
/TxD: J4.2, U39.8 (3Y)
/~9000-9FFF: U30.14 (Y1), U33.2, U34.5
/~CAS: R16.1, U22.15 (~CAS), U23.15 (~CAS), U24.15 (~CAS), U25.15 (~CAS), U26.15 (~CAS), U27.15 (~CAS), U28.15 (~CAS), U29.15 (~CAS)
/~IRQ: J1.37, U13.3 (~IRQ), U17.4 (~IRQ), U40.26 (~IRQ)
/~NMI: J1.35, U13.2 (~NMI), U17.6 (~NMI)
/~NOROM: J1.36, Q4.2 (C)
/~RAM/ROM: U37.5 (Q), U50.1
/~RAS: R17.1, U22.4 (~RAS), U23.4 (~RAS), U24.4 (~RAS), U25.4 (~RAS), U26.4 (~RAS), U27.4 (~RAS), U28.4 (~RAS), U29.4 (~RAS)
/~RES: J1.1, Q1.2 (C), U5.3, U16.12, U40.4 (~RES), U41.12 (~RST)
/~SO: J1.3, U17.38 (~SO)
GND: C3.2, C4.2, C5.2, C6.2, C7.2, C8.2, C9.2, C10.2, C11.2, C12.1, C13.1, C14.2, C15.2, C16.2, C17.2, C18.2, C19.2, C20.2, C21.2, C22.2, C23.2, C24.2, C25.2, C26.2, C27.2, C28.2, C29.2, C30.2, C31.2, C32.2, C33.2, C34.2, C35.2, C36.2, C37.2, C38.2, C39.2, C40.1, C41.2, J1.20, J1.40, J2.4, J2.7, J4.7, J5.1, J5.2, Q1.3 (E), Q2.3 (E), Q4.3 (E), Q5.3 (E), R20.2, R25.1, U1.7 (GND), U2.7 (GND), U3.2 (MR), U3.7 (GND), U3.12 (MR), U4.2 (R0(1)), U4.3 (R0(2)), U4.10 (GND), U5.7 (GND), U6.7 (GND), U7.8 (GND), U8.8 (GND), U8.15 (E), U9.8 (GND), U9.15 (E), U10.8 (GND), U10.15 (E), U11.3 (I1a), U11.8 (GND), U11.15 (E), U12.8 (GND), U13.1 (GND), U14.7 (GND), U15.7 (GND), U16.7 (GND), U17.1 (Vss), U17.21 (Vss), U18.1 (OEa)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
unnamed: J2.1, SW1.1, U35.15 (Q5)
unnamed: J2.3, R18.2, SW1.3, U1.13
unnamed: J2.5, SW2.1, U35.12 (Q4)
unnamed: J2.6, R1.1, R5.1, SW2.3, U1.9, U2.9, U2.39, U12.9 (A), U13.39 (TSC), U16.13, U50.2
unnamed: Q1.1 (B), R4.2
unnamed: Q2.1 (B), R5.2
unnamed: Q2.2 (C), R6.1
unnamed: Q3.2 (B), R6.2, R7.1
unnamed: Q3.1 (C), VR1.1 (IN)
unnamed: Q4.1 (B), R20.1, R21.1
unnamed: Q5.1 (B), R22.2
unnamed: R16.2, U15.6
unnamed: R17.2, U16.6
unnamed: U1.6, U34.4
unnamed: U1.10, U32.5
unnamed: U1.12, U34.13
unnamed: U2.4, U50.5
unnamed: U2.5, U31.8
unnamed: U2.6, U50.4
unnamed: U4.9 (Q1), U5.10
unnamed: U4.8 (Q2), U5.9
unnamed: FB2.2, U6.8 (CLK)
unnamed: U2.13, U6.4 (QB), U7.2 (I0a), U7.10 (I1c)
unnamed: U6.5 (QC), U7.11 (I0c), U7.13 (I1d)
unnamed: U1.1, U6.6 (QD), U7.14 (I0d)
unnamed: U2.1, U6.12 (QG)
unnamed: C3.1, FB1.2, U6.14 (VCC)
unnamed: U8.4 (Za), U10.2 (I0a)
unnamed: U8.7 (Zb), U10.5 (I0b)
unnamed: U8.9 (Zc), U10.11 (I0c)
unnamed: U8.12 (Zd), U10.14 (I0d)
unnamed: U1.4, U3.1 (CP), U10.1 (S), U11.1 (S)
unnamed: R11.1, U10.4 (Za)
unnamed: R10.1, U10.7 (Zb)
unnamed: R9.1, U10.9 (Zc)
unnamed: R8.1, U10.12 (Zd)
unnamed: U9.4 (Za), U11.2 (I0a)
unnamed: U9.7 (Zb), U11.5 (I0b)
unnamed: U9.9 (Zc), U11.11 (I0c)
unnamed: U9.12 (Zd), U11.14 (I0d)
unnamed: R15.1, U11.4 (Za)
unnamed: R14.1, U11.7 (Zb)
unnamed: R13.1, U11.9 (Zc)
unnamed: R12.1, U11.12 (Zd)
unnamed: U1.8, U12.1 (A), U13.40 (~HALT)
unnamed: C2.2, U12.14 (Cext)
unnamed: C2.1, R3.2, U12.15 (RCext)
unnamed: U5.4, U12.4 (~Q)
unnamed: C1.2, U12.6 (Cext)
unnamed: R4.1, U12.5 (Q)
unnamed: C1.1, R2.2, U12.7 (RCext)
unnamed: U5.5, U12.12 (~Q)
unnamed: U1.2, U13.35 (Q)
unnamed: U5.6, U13.37 (~RESET), U17.40 (~RES), U36.1 (~Mr)
unnamed: U2.12, U14.3 (C)
unnamed: U14.6 (~Q), U16.4
unnamed: U6.11 (QF), U14.1 (~R)
unnamed: U7.4 (Za), U14.11 (C)
unnamed: U14.8 (~Q), U16.5
unnamed: U2.2, U14.13 (~R)
unnamed: U15.1, U15.2, U16.1, U34.3
unnamed: U15.3, U15.4
unnamed: U15.10, U43.6
unnamed: U15.11, U33.10
unnamed: U16.8, U32.2, U32.12
unnamed: U2.10, U16.9
unnamed: U16.3, U21.19 (CE)
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

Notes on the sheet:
UNUSED UNITS
The CommonPET
R/~{W}
PURPLE
SuperPET Waterloo $A and $B (U47)
PRG
DECOUPLING
SuperPET Waterloo $C and $D (U48)
6502
SuperPET Waterloo $E and $F 50Hz (U49)
6809
was forgotton in first ASSY
R25 in later revisions, not on 324100
added in later versions located at place of FB2
bridged with factory bodge on ASSY 324100 removed in later revisions

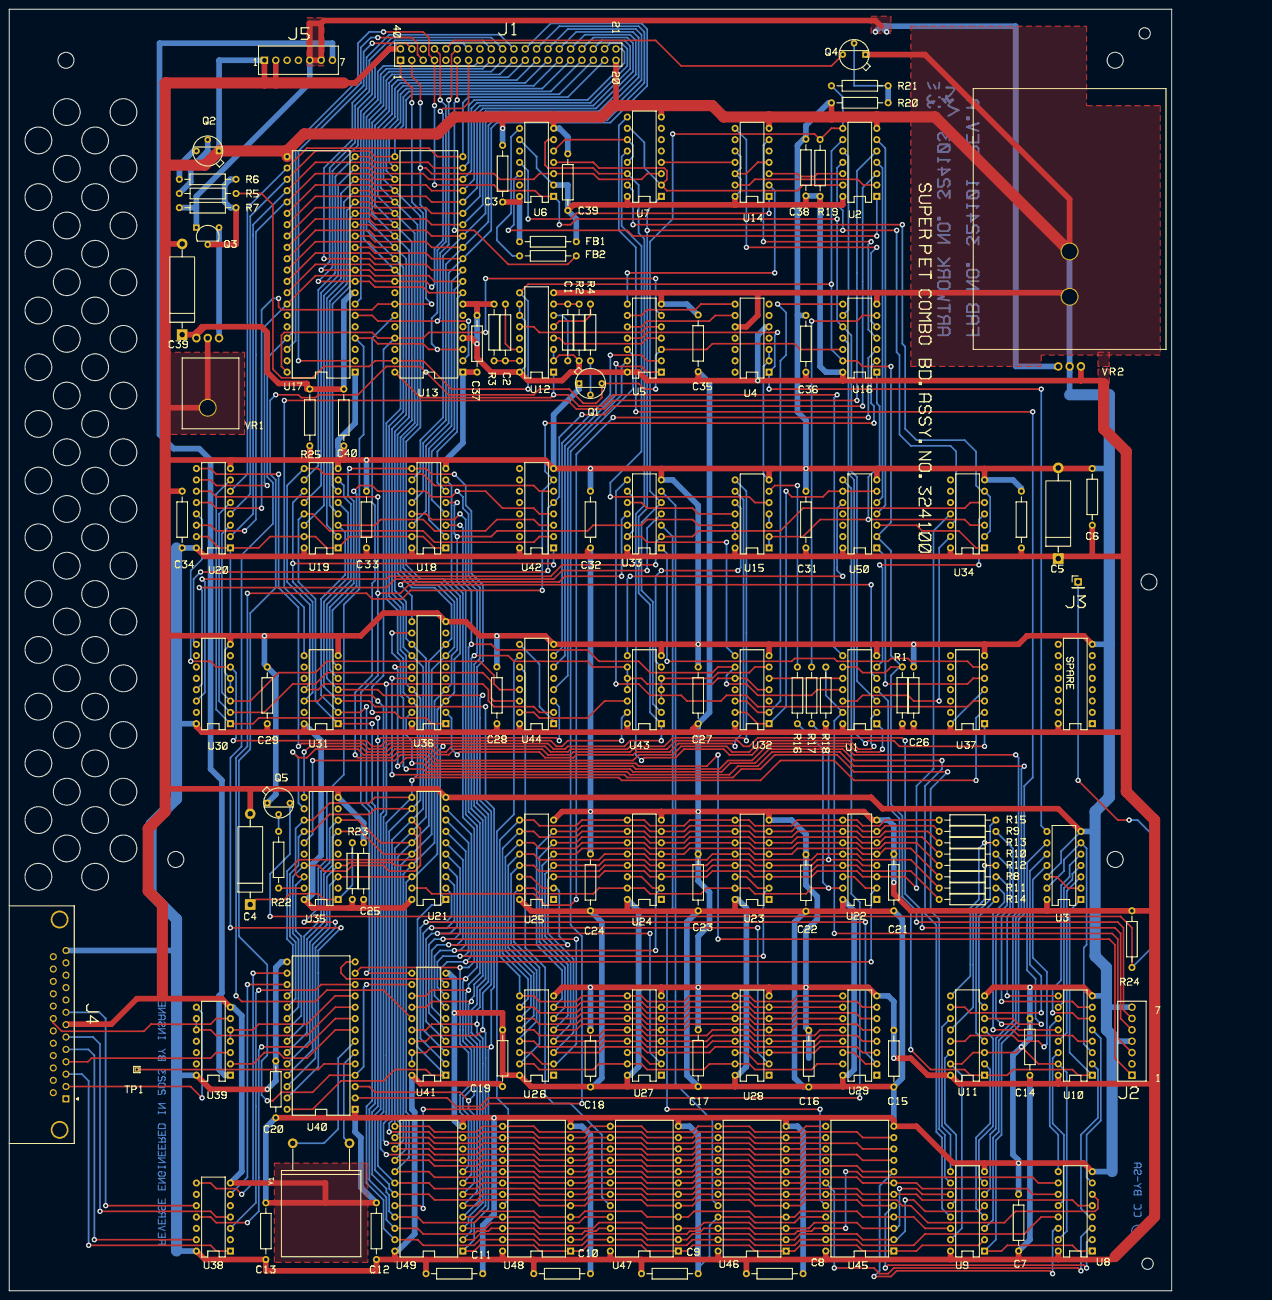
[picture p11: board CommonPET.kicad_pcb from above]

Board: 2 copper layers, 280.7 x 287.0 mm, 133 parts (0 on the bottom side), 208 nets.

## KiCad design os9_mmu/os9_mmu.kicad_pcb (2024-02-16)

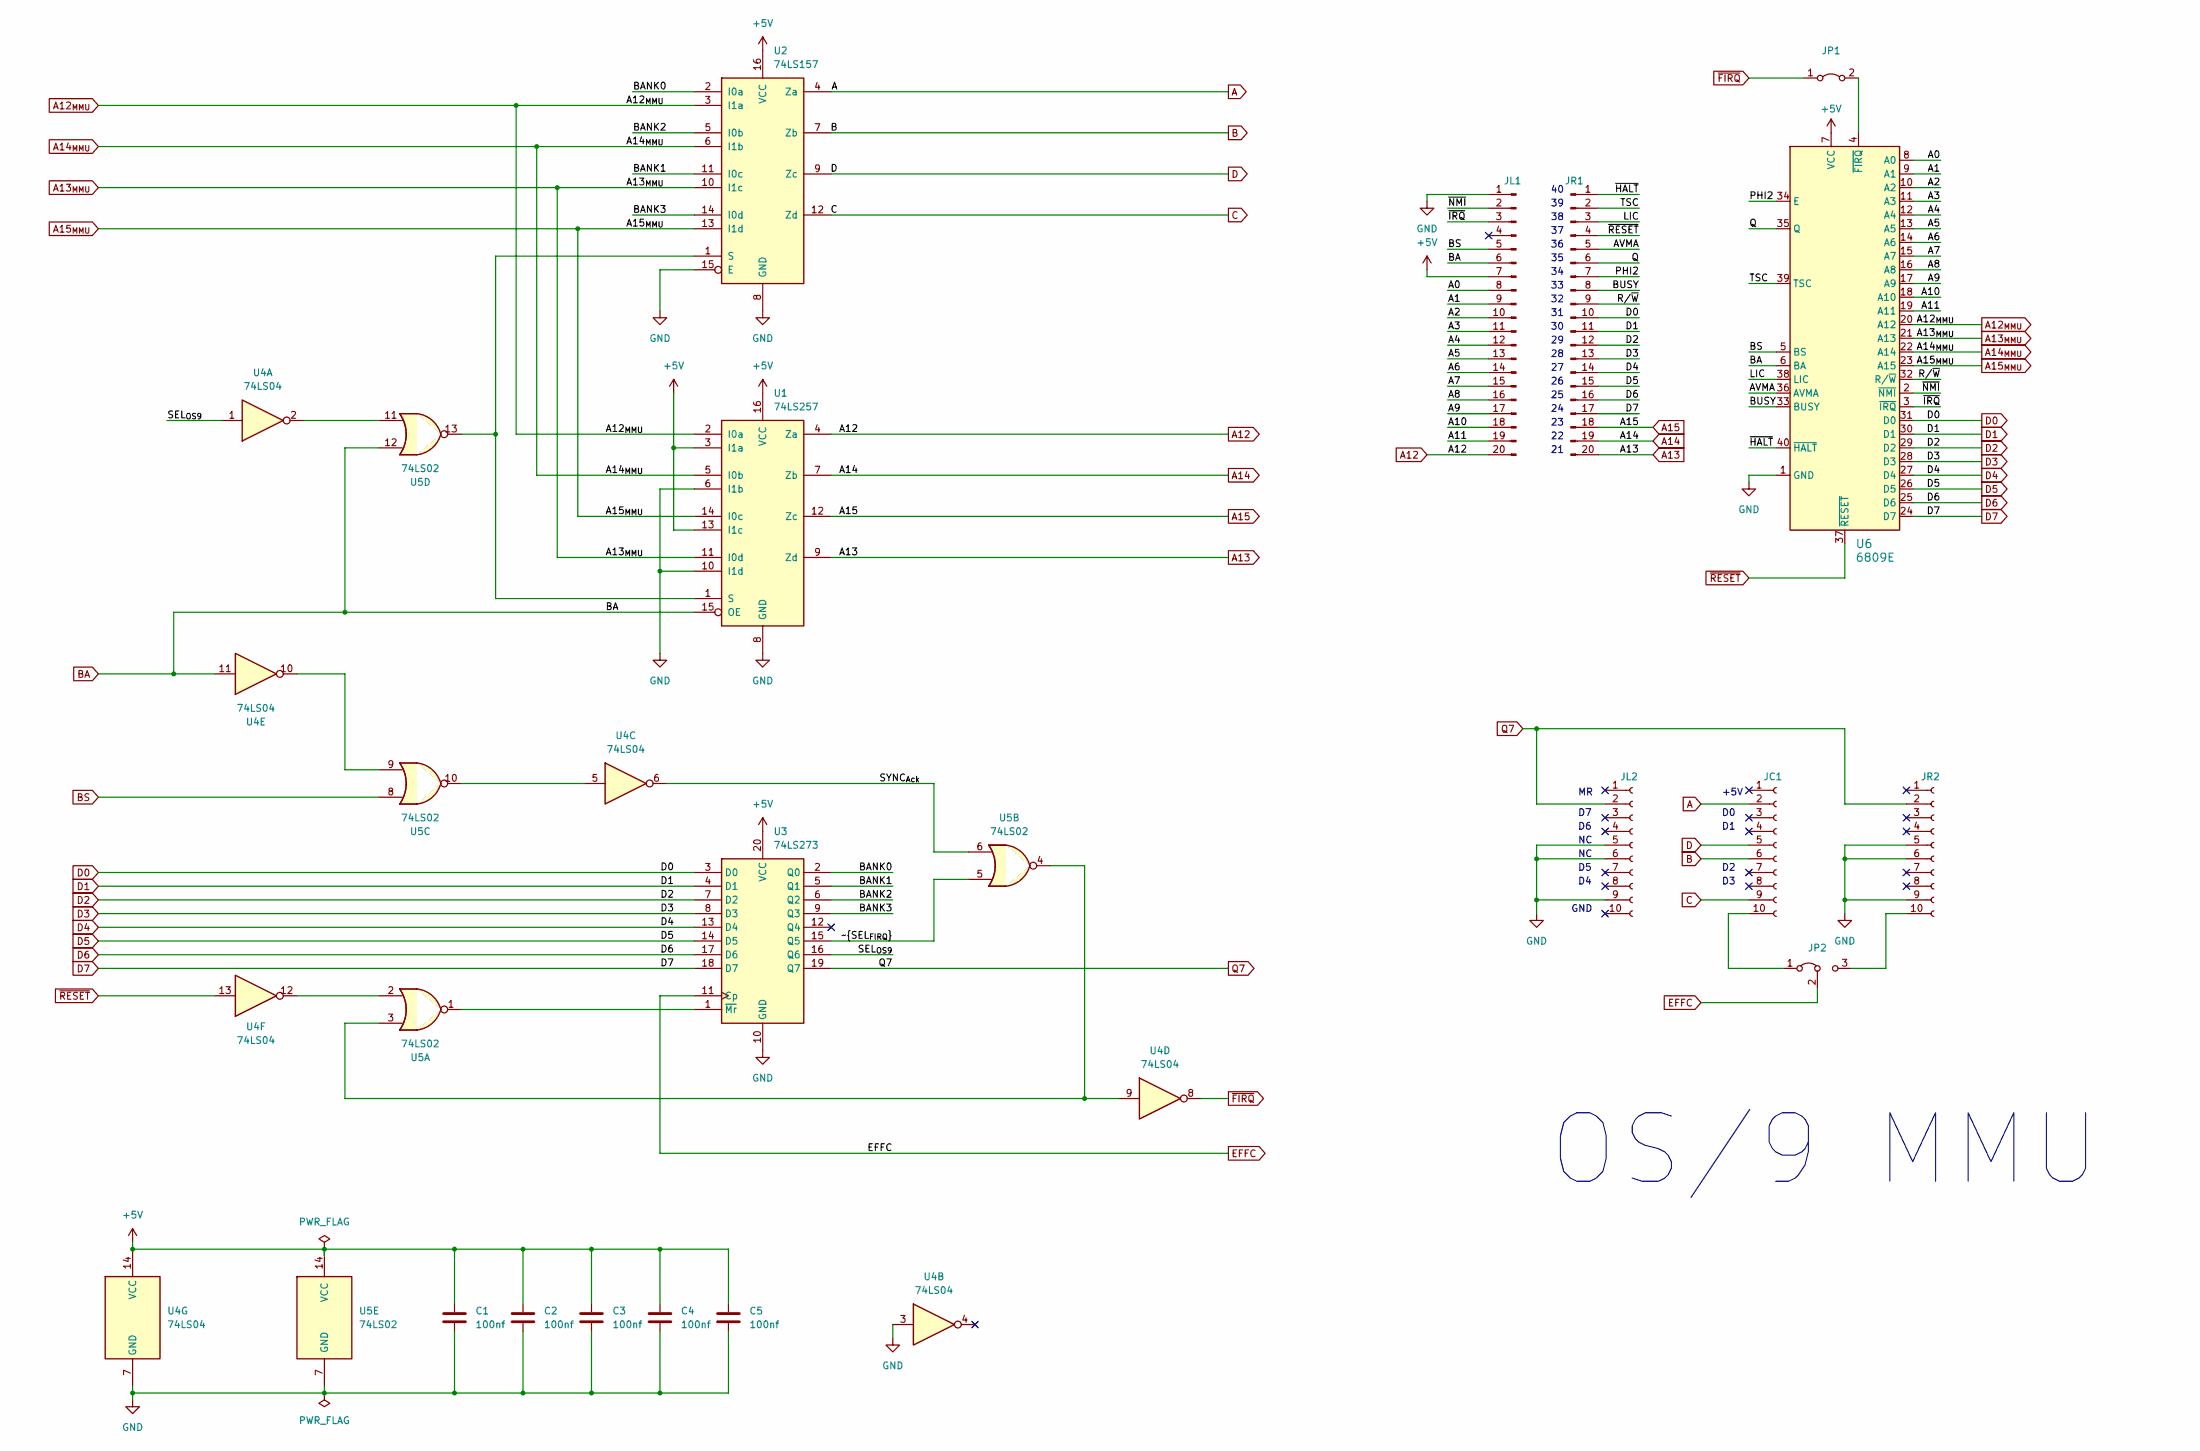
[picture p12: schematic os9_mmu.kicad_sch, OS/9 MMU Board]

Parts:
C1, C2, C4, C5: 100nf; C_Disc_D5.0mm_W2.5mm_P2.50mm
C3: 100nf; C_Disc_D5.0mm_W2.5mm_P5.00mm
JC1: Conn_01x10_Pin; PinSocket_1x10_P2.54mm_Vertical
JL1: Conn_01x20_Pin; PinHeader_1x20_P2.54mm_Vertical
JL2: Conn_01x10_Pin; PinSocket_1x10_P2.54mm_Vertical
JP1: Jumper_2_Bridged; PinHeader_1x02_P2.54mm_Vertical
JP2: Jumper_3_Bridged12; PinHeader_1x03_P2.54mm_Vertical
JR1: Conn_01x20_Pin; PinHeader_1x20_P2.54mm_Vertical
JR2: Conn_01x10_Pin; PinSocket_1x10_P2.54mm_Vertical
U1: 74LS257; DIP-16_W7.62mm_LongPads
U2: 74LS157; DIP-16_W7.62mm_LongPads
U3: 74LS273; DIP-20_W7.62mm_LongPads
U4: 74LS04; DIP-14_W7.62mm_LongPads
U5: 74LS02; DIP-14_W7.62mm_LongPads
U6: 6809E; DIP-40_W15.24mm_Socket_LongPads

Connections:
+5V: C1.1, C2.1, C3.1, C4.1, C5.1, JL1.7, U1.3 (I1a), U1.13 (I1c), U1.16 (VCC), U2.16 (VCC), U3.20 (VCC), U4.14 (VCC), U5.14 (VCC), U6.7 (VCC)
/A0: JL1.8, U6.8 (A0)
/A1: JL1.9, U6.9 (A1)
/A2: JL1.10, U6.10 (A2)
/A3: JL1.11, U6.11 (A3)
/A4: JL1.12, U6.12 (A4)
/A5: JL1.13, U6.13 (A5)
/A6: JL1.14, U6.14 (A6)
/A7: JL1.15, U6.15 (A7)
/A8: JL1.16, U6.16 (A8)
/A9: JL1.17, U6.17 (A9)
/A10: JL1.18, U6.18 (A10)
/A11: JL1.19, U6.19 (A11)
/AVMA: JR1.5, U6.36 (AVMA)
/BANK0: U2.2 (I0a), U3.2 (Q0)
/BANK1: U2.11 (I0c), U3.5 (Q1)
/BANK2: U2.5 (I0b), U3.6 (Q2)
/BANK3: U2.14 (I0d), U3.9 (Q3)
/BUSY: JR1.8, U6.33 (BUSY)
/LIC: JR1.3, U6.38 (LIC)
/PHI2: JR1.7, U6.34 (E)
/Q: JR1.6, U6.35 (Q)
/R/~W: JR1.9, U6.32 (R/~W)
/SEL_{OS9}: U3.16 (Q6), U4.1
/SYNC_{Ack}: U4.6, U5.6
/TSC: JR1.2, U6.39 (TSC)
/~HALT: JR1.1, U6.40 (~HALT)
/~IRQ: JL1.3, U6.3 (~IRQ)
/~NMI: JL1.2, U6.2 (~NMI)
/~SEL_{FIRQ}: U3.15 (Q5), U5.5
A: JC1.2, U2.4 (Za)
A12: JL1.20, U1.4 (Za)
A12_{MMU}: U1.2 (I0a), U2.3 (I1a), U6.20 (A12)
A13: JR1.20, U1.9 (Zd)
A13_{MMU}: U1.11 (I0d), U2.10 (I1c), U6.21 (A13)
A14: JR1.19, U1.7 (Zb)
A14_{MMU}: U1.5 (I0b), U2.6 (I1b), U6.22 (A14)
A15: JR1.18, U1.12 (Zc)
A15_{MMU}: U1.14 (I0c), U2.13 (I1d), U6.23 (A15)
B: JC1.6, U2.7 (Zb)
BA: JL1.6, U1.15 (OE), U4.11, U5.12, U6.6 (BA)
BS: JL1.5, U5.8, U6.5 (BS)
C: JC1.9, U2.12 (Zd)
D: JC1.5, U2.9 (Zc)
D0: JR1.10, U3.3 (D0), U6.31 (D0)
D1: JR1.11, U3.4 (D1), U6.30 (D1)
D2: JR1.12, U3.7 (D2), U6.29 (D2)
D3: JR1.13, U3.8 (D3), U6.28 (D3)
D4: JR1.14, U3.13 (D4), U6.27 (D4)
D5: JR1.15, U3.14 (D5), U6.26 (D5)
D6: JR1.16, U3.17 (D6), U6.25 (D6)
D7: JR1.17, U3.18 (D7), U6.24 (D7)
EFFC: JP2.2 (C), U3.11 (Cp)
GND: C1.2, C2.2, C3.2, C4.2, C5.2, JL1.1, JL2.5, JL2.6, JL2.9, JR2.5, JR2.6, JR2.9, U1.6 (I1b), U1.8 (GND), U1.10 (I1d), U2.8 (GND), U2.15 (E), U3.10 (GND), U4.3, U4.7 (GND), U5.7 (GND), U6.1 (GND)
unnamed: JC1.10, JP2.1 (A)
unnamed: JP1.2 (B), U6.4 (~FIRQ)
unnamed: JP2.3 (B), JR2.10
unnamed: U1.1 (S), U2.1 (S), U5.13
unnamed: U3.1 (~Mr), U5.1
unnamed: U4.2, U5.11
unnamed: U4.5, U5.10
unnamed: U4.9, U5.3, U5.4
unnamed: U4.10, U5.9
unnamed: U4.12, U5.2
Q7: JL2.2, JR2.2, U3.19 (Q7)
~FIRQ: JP1.1 (A), U4.8
~RESET: JR1.4, U4.13, U6.37 (~RESET)

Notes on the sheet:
GND
OS/9 MMU
+5V

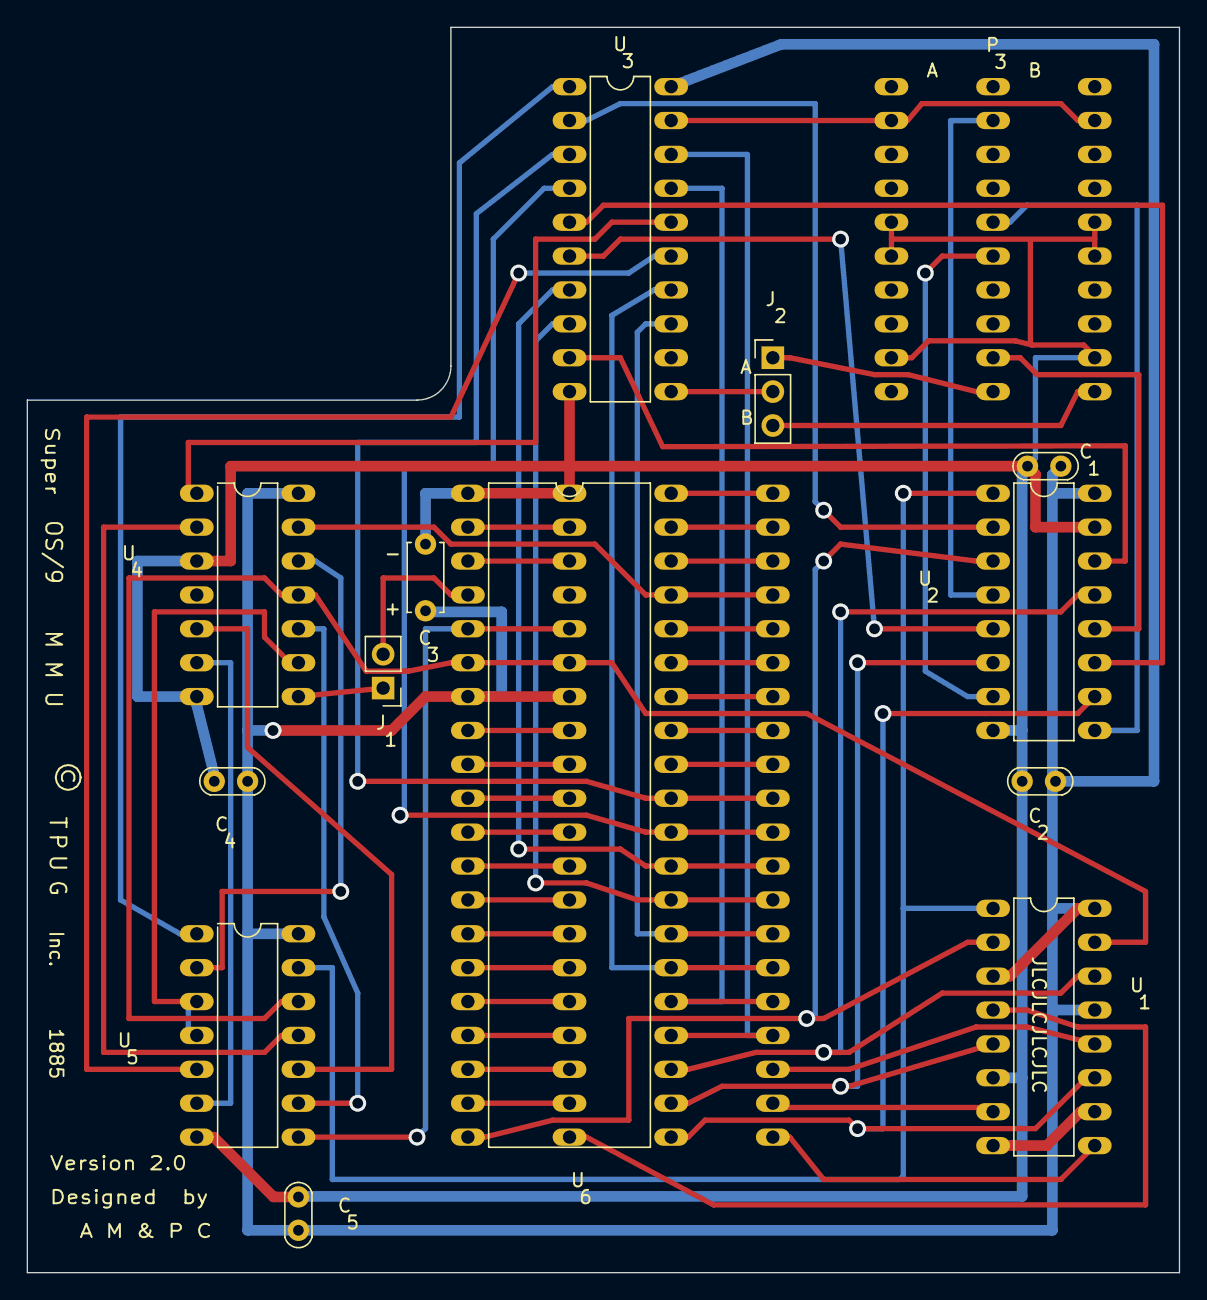
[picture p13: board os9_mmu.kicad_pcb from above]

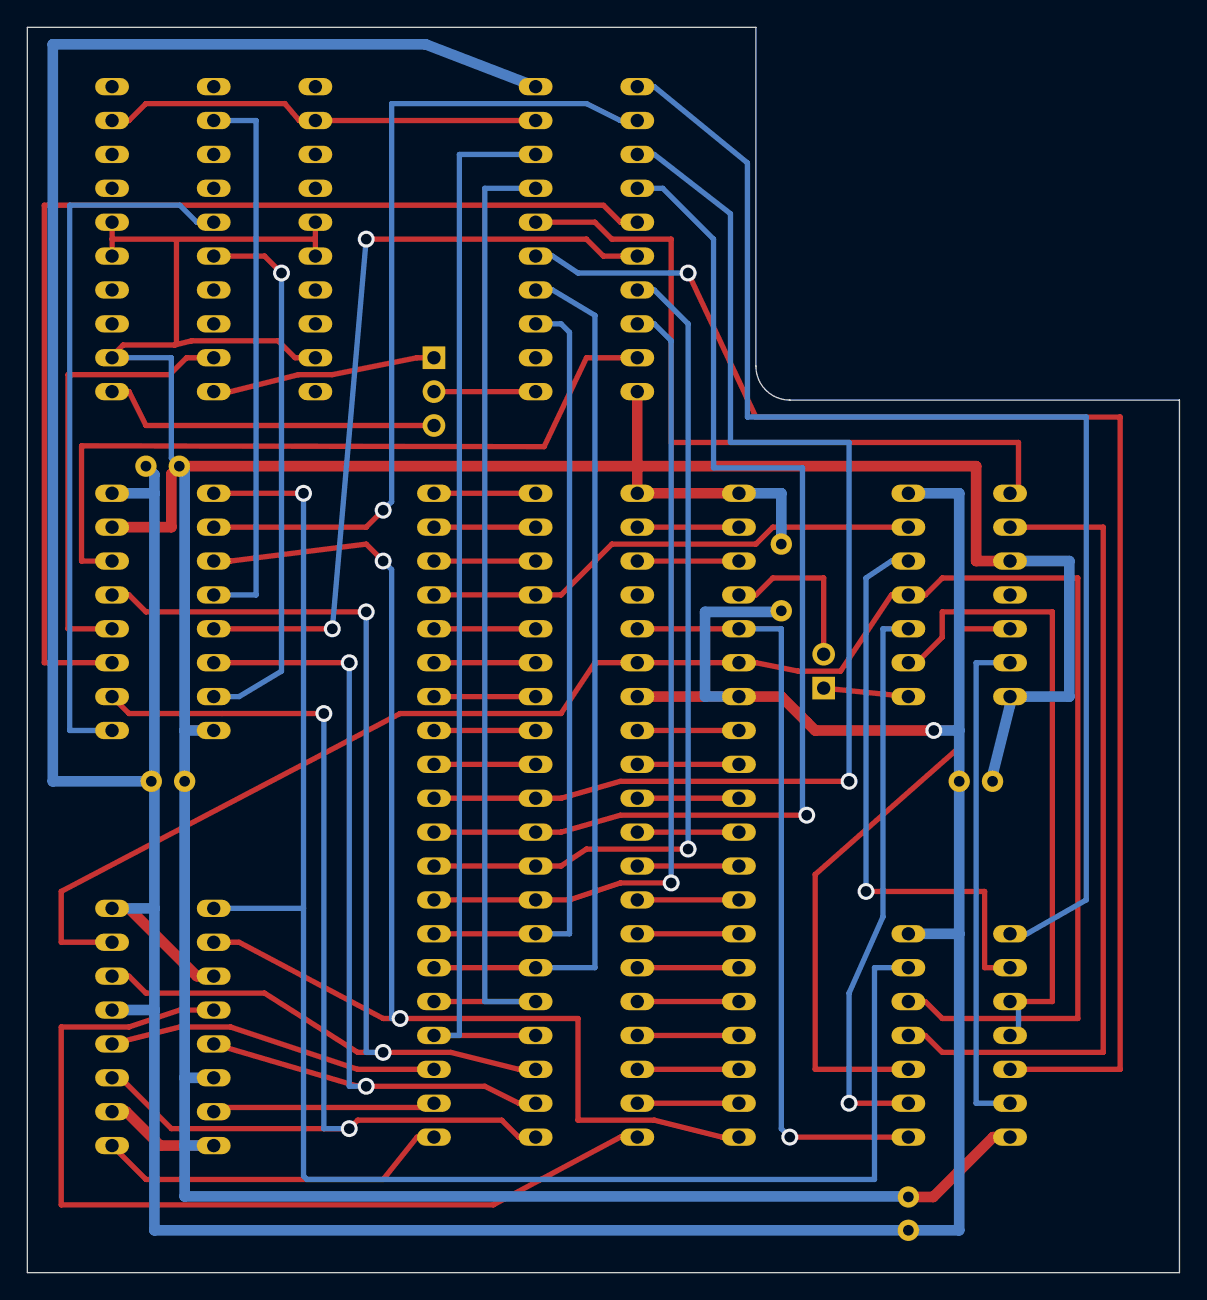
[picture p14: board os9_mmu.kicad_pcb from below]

Board: 2 copper layers, 86.4 x 93.3 mm, 18 parts (2 on the bottom side), 67 nets.

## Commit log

2023-10-30 Added traces and netlist to BOM
    - the BOM now contains the graphical representation of all traces and nets
2023-10-30 Cosmetic datasheet fixes
    - fixed position of U35 designator to not be overlapping that of Q5
    - added proper links to datasheets of 74LS393
    [CommonPET.kicad_sch]
2024-02-16 MMU adjustments
    -adjusted power trace widths
    -reintroduced solder mask layer - was absence to give board a vintage look but makes silkscreen prints impossible
    -fixed license links in drawing sheets to match board prints, readme and project
    [os9_mmu.kicad_pcb, os9_mmu.kicad_sch]
2024-02-16 kicad drawing sheet fixes
    fixed license links in drawing sheets to match board prints, readme and project
    [CommonPET.kicad_pcb, CommonPET.kicad_sch]

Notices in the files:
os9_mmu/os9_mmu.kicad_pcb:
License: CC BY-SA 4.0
